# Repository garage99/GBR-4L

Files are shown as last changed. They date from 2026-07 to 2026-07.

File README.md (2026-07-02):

# GBR-4L

GBR-4L is a self-powered USB 2.0 carrier for four Semtech (formerly Sierra
Wireless) AirPrime EM7565 LTE modules. It is intended for use with
OpenMPTCProuter and for manufacture by JLCPCB.

## Rev 1.0 baseline

- Four EM7565 modules in M.2 Key B 3042 sockets
- One nano-SIM per modem
- USB 2.0 High-Speed upstream through a USB Type-C receptacle
- Four-port USB 2.0 hub
- 12 V external input
- Four independently controlled 3.3 V modem power rails
- Per-modem `RESET#`, `W_DISABLE1#`, status indication, and test points
- Four-layer PCB: signal / ground / power / signal
- Preferred outline: 160 mm x 100 mm

> EM7565 is an M.2 module, not a Mini PCIe card. The USB Type-C connector is an
> upstream-facing USB device port (UFP), even though it connects to the host PC.

## Repository layout

- `Hardware/KiCad/GBR-4L/` — KiCad 10 project
- `Hardware/Design/` — requirements, design decisions, and interface definitions
- `Hardware/BOM/` — preliminary and released bills of materials
- `Firmware/` — reserved for optional control firmware
- `Case/` — enclosure and mechanical data

## Current milestone

M1 (part selection and electrical architecture) is in progress. The initial
architecture is recorded in
[`Hardware/Design/GBR-4L_Rev1_Design_Baseline.md`](Hardware/Design/GBR-4L_Rev1_Design_Baseline.md).
No Gerber files are released yet.

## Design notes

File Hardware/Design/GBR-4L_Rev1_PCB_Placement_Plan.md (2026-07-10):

# GBR-4L Rev 1 PCB placement plan

Status: functional placement and plane baseline before detailed routing
Board: 160 mm x 100 mm, 1.6 mm, four copper layers

## Layer intent

| Layer | Primary use |
|---|---|
| F.Cu | Components, USB differential pairs, short local power routing, GND pour |
| In1.Cu | Uninterrupted ground plane |
| In2.Cu | 12 V and five 3.3 V power regions |
| B.Cu | Low-speed control, secondary power routing, GND pour |

Do not split the ground plane below USB, SIM, clock, or modem control traces.
Any layer transition for USB requires adjacent ground stitching vias.

`In1.Cu` now contains the filled `IN1_SOLID_GND` zone, inset 0.5 mm from the
board edge with 0.25 mm local clearance.

`F.Cu` and `B.Cu` also contain filled GND pours inset 0.5 mm from the board
edge. They use 0.25 mm local clearance, 0.30 mm thermal gaps and spokes, and
remove isolated copper islands below 5 mm². The 44 GND stitching vias connect
both outer pours to the uninterrupted `In1.Cu` reference plane.

`In2.Cu` now contains six isolated filled regions:

- `+12V_PROTECTED` and `+3V3_SYS` in the upper half;
- `+3V3_M1` through `+3V3_M4` in four independent modem columns.

Adjacent regions have a 1.0 mm nominal boundary gap and 0.30 mm zone
clearance.

## Via baseline

- Each modem rail (`+3V3_M1` through `+3V3_M4`) has a four-via connection
  array below its M.2 socket: 1.20 mm diameter with a 0.60 mm finished drill.
- `+12V_PROTECTED` has a four-via 1.50/0.80 mm array and `+3V3_SYS` has a
  four-via 1.20/0.60 mm array in their respective upper power regions. A
  second two-via 1.20/0.60 mm `+3V3_SYS` feed connects the USB hub locally,
  with one additional local feed at its reset pull-up.
- The ground plane has 71 stitching, thermal, and local return vias around the board
  perimeter, beside the four modem power arrays, and at both Type-C GND
  contacts: 0.60 mm
  diameter with a 0.30 mm finished drill. This count includes a dedicated via
  and short 0.50 mm ground connection at the USB ESD clamp plus individual
  returns for the shield termination parts, the USB VBUS detector divider, and
  four 0.50/0.25 mm local return vias beside USB2 layer transitions.
- Three additional 0.60/0.30 mm vias connect both Type-C shell ends and the
  R3/C1 termination node between the outer layers on `USB_SHIELD`. This net
  remains intentionally separate from digital GND.
- Two 0.45/0.20 mm signal vias route `USB_VBUS_DET` from the hub to the local
  divider while avoiding the already-routed reset and decoupling area.
- Two additional 0.45/0.20 mm signal vias route `USB_VBUS` from the Type-C
  entry and ESD clamp to the detector divider.
- Four additional 0.45/0.20 mm signal vias route the two Type-C CC pins to
  their pull-down resistors while leaving the USB2 D+/D- corridor open.
- Six 0.40/0.20 mm signal vias gather the duplicated Type-C D+/D- contacts
  into the USB ESD clamp input pins on short provisional `B.Cu` escapes.
- Four additional 0.40/0.20 mm signal vias route the protected upstream USB2
  pair from the ESD clamp output pins to the USB2514B upstream pins.
- Four additional 0.40/0.20 mm signal vias route USB hub downstream port 1 to
  the first M.2 modem socket (`J101`) on provisional `B.Cu` pair segments.
- Four additional 0.40/0.20 mm signal vias route USB hub downstream port 2 to
  the second M.2 modem socket (`J201`) on a separate provisional `B.Cu` lane.
- All 129 vias are through vias from `F.Cu` to `B.Cu`; all nine copper zones
  have been refilled after placement.

These are plane-access points, not completed load connections. The power
arrays must be tied to their regulator and M.2 power pads with short, wide
copper during detailed routing. Add local ground return vias beside USB layer
transitions and decoupling capacitors when their final positions are frozen.

The five 3.3 V contacts on each M.2 socket are now fanned out on `F.Cu` to its
four-via power array. The contact exits use 0.25 mm neck-downs, merge through
0.50 mm branches, and transition to 1.00 mm trunks. This completes the local
socket-to-plane connection for `+3V3_M1` through `+3V3_M4`; the regulator side
of each power region remains to be routed.

## Provisional net classes

- `USB2_HS_PROVISIONAL`: 0.20 mm width / 0.20 mm pair gap. Replace these
  provisional values with the 90-ohm geometry calculated from the selected
  JLCPCB stack-up before routing.
- `MODEM_3V3_POWER`: 1.00 mm track, 1.20/0.60 mm via.
- `INPUT_12V_POWER`: 1.50 mm track, 1.50/0.80 mm via.

These are routing defaults, not proof of current capacity or impedance. Power
rails should use pours where practical and must be validated thermally.

## Mechanical baseline

- Rectangular 160 mm x 100 mm Edge.Cuts outline.
- Four M3 mounting holes, each centered 5 mm from its two adjacent edges.
- Maintain mounting-hole copper and component keep-outs after enclosure review.
- User-accessible connectors, SIM sockets, LEDs, and buttons face board edges.

## Functional placement

1. Place the USB Type-C receptacle and ESD device at one board edge.
2. Place USB2514B, its 24 MHz crystal, and upstream passives immediately behind
   the Type-C receptacle.
3. Arrange the four M.2 3042 sockets so module antenna connectors and coax
   cables remain accessible.
4. Place each nano-SIM socket near its associated modem and at an accessible
   edge.
5. Group the 12 V protection stage and five buck regulators away from USB,
   SIM, and the antenna-connector ends of all modem modules.
6. Keep each buck switch-node copper compact; do not route it on an inner
   layer.

## Footprint status

- TE Connectivity 2199230-1 M.2 Key B footprint is captured from customer
  drawing C-2199230 Rev B4.
- TE Connectivity 2452808-1 nano-SIM footprint is captured from customer
  drawing C-2452808 Rev C1; verify the first incoming part against the land
  pattern before assembly release.
- GCT USB4105 signal and shell tails are captured from the manufacturer
  drawing with the four physically merged contact pairs represented as single
  pads.
- Final 12 V input connector, blade-fuse holder, PMOS, and inductor choices.
- Crystal load-capacitance and package selection.

The current PCB contains the layer stack, outline, mounting holes, all 188
schematic footprints, and all 287 schematic nets. Four M.2 sockets are anchored
on a common line with 30 mm x 42 mm module envelopes reserved below them. The
12 V input and USB Type-C receptacle are anchored at opposite board edges. All
remaining parts are collision-free in the upper component band.

The USBLC6-2SC6 ESD clamp (`U1`) is now placed directly behind the Type-C
receptacle. Its ground pin has a dedicated plane via. The `+3V3_SYS` inductor
`L801` was relocated within the same upper power region to open this protected
USB entry corridor.

The Type-C upstream D+/D- contacts are routed from `J1` to the input side of
the ESD clamp (`U1`) using short 0.15 mm provisional `F.Cu` stubs and `B.Cu`
gathering traces. The protected side of `U1` is also routed to `U2` pins 30
and 31 with provisional 0.15 mm `B.Cu` pair segments and short `F.Cu` pin
escapes. This completes the upstream USB2 electrical path from connector to
hub, but the geometry must still be recalculated and tuned after the final
JLCPCB stack-up is selected. Four local GND return vias are placed next to the
connector-side and hub-side USB2 layer transitions.

The 1 MΩ / 4.7 nF shield termination (`R3`/`C1`) is placed below the Type-C
receptacle. Both parts have individual GND vias, while their `USB_SHIELD` pads
join at a dedicated via and connect to the shell on `B.Cu`.

The two 5.1 kΩ Type-C pull-downs (`R1`/`R2`) are grouped below the connector
and each has an individual GND via. Their `USB_CC1` and `USB_CC2` sides are
routed to the Type-C receptacle with short `F.Cu` escapes and `B.Cu` vertical
runs.

USB hub downstream port 1 (`USB_M1_D+`/`USB_M1_D-`) is routed from `U2` pins
1 and 2 to `J101` pins 7 and 9. The route uses short `F.Cu` pin escapes, then
travels on `B.Cu` along the lane above the M.2 sockets before returning to the
connector pads. This is also provisional USB2 geometry pending final stack-up
and length/impedance tuning.

USB hub downstream port 2 (`USB_M2_D+`/`USB_M2_D-`) is routed from `U2` pins
3 and 4 to `J201` pins 7 and 9. It follows the same provisional style as port
1, but uses an offset `B.Cu` lane so the two modem USB2 routes do not overlap.

The USB2514B hub (`U2`) is placed at (145 mm, 55 mm), between the Type-C entry
and four modem sockets. Its 4.1 mm exposed GND pad contains a 2 x 2 array of
0.60/0.30 mm thermal vias. These vias are open on the component side and
tented on `B.Cu`; confirm the selected assembler accepts this via-in-pad
construction before release.

The 24 MHz crystal (`Y1`) and 12 pF C0G load capacitors (`C4`/`C5`) are placed
immediately left of `U2`. Both oscillator traces are routed directly on
`F.Cu`, without vias, and each load capacitor has an individual GND via.

The hub reference filter and bias parts (`C2`, `C3`, and `R6`) are also placed
at their associated `U2` pins. Each sensitive node is routed directly on
`F.Cu`, and every part has its own short GND return and plane via.

Four 100 nF capacitors (`C7` through `C10`) and the 4.7 µF bulk bypass (`C11`)
surround `U2`. Their 3.3 V branches are routed directly to the nearest hub
power pins, and all five parts use individual GND vias. The resulting
decoupling network is tied to the `+3V3_SYS` inner region through two local
power vias and a 1.00 mm `F.Cu` trunk.

The hub reset network (`R7`/`C6`) is placed above the right side of `U2`.
`HUB_RESET#` uses a short `B.Cu` escape between two vias to pass the
decoupling area, with a local `+3V3_SYS` pull-up via and a dedicated capacitor
GND return.

The USB VBUS detector divider (`R4`/`R5`) is placed in the same USB support
area near `U2`. Its midpoint is routed to `U2` pin 27 (`USB_VBUS_DET`) using
two small signal vias and a short `B.Cu` segment. `R5` has a local GND return
via. The `USB_VBUS` side of `R4` is now tied to both Type-C VBUS contacts and
the USB ESD clamp VBUS pin through a short `F.Cu` entry trunk and a `B.Cu`
escape to the divider.

This is the functional anchor baseline, not the final local placement. Buck
converter loops, hub passives, SIM protection, modem decoupling, buttons, and
LEDs must next be pulled tightly around their associated primary components.

The two 0.65 mm USB4105 locating holes are presently shown on `F.Fab` rather
than emitted as NPTH holes. KiCad 10.0.4 CLI aborts during DRC when those NPTH
holes are combined with the adjacent fine-pitch pads. They must be restored as
NPTH holes and verified in a newer KiCad release before fabrication output.

Electrical nets remain authoritative in the schematic. The current PCB has
all 287 schematic nets imported through KiCad's **Update PCB from Schematic**
workflow.

## Placement review gate

- Verify the imported set remains at 287 schematic nets after any schematic
  change and **Update PCB from Schematic** operation.
- Verify zero missing footprint assignments.
- Check M.2 module and antenna-cable keep-outs in 3D.
- Confirm SIM insertion direction and finger clearance.
- Confirm all edge controls against the enclosure.
- Calculate 90-ohm USB geometry from the selected JLCPCB stack-up.
- Run PCB DRC before beginning routing.

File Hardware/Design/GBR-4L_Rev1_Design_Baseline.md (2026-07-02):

# GBR-4L Rev 1.0 design baseline

Status: engineering baseline for schematic capture<br>
Target CAD: KiCad 10<br>
Target fabrication: JLCPCB, four layers

## 1. Purpose

GBR-4L connects four AirPrime EM7565 LTE modems to one OpenMPTCProuter host over
USB 2.0. Each modem has its own nano-SIM, controllable power rail, reset,
wireless-disable signal, status LED, and measurement points.

This document resolves ambiguities in the original project brief. It is the
source of truth until superseded by an approved revision.

## 2. Corrections to the original brief

1. **Module form factor:** EM7565 is M.2 Key B, size 3042. It is not Mini PCIe.
2. **USB role:** the Type-C receptacle is an upstream-facing device port (UFP).
   The attached computer/OpenMPTCProuter is the USB host.
3. **RF routing:** cellular RF remains on the EM7565 module and exits through
   its miniature coaxial connectors. The carrier PCB does not route cellular
   RF transmission lines. Placement must preserve antenna-cable access and
   keep switching regulators away from the module antenna-connector end.
4. **Data-rate expectation:** Rev 1 uses USB 2.0 High-Speed. Aggregate practical
   throughput is therefore bounded by the single USB 2.0 upstream link and
   will be far below the sum of four Cat-12 modem peak rates.

## 3. Electrical architecture

### 3.1 Power tree

Nominal input is 12 V DC. Design input range is 10.8 V to 13.2 V.

```text
12V_IN
  |
  +-- input fuse / reverse-polarity protection / TVS
  |
  +-- 3 A buck 1 --> MODEM_1_3V3
  +-- 3 A buck 2 --> MODEM_2_3V3
  +-- 3 A buck 3 --> MODEM_3_3V3
  +-- 3 A buck 4 --> MODEM_4_3V3
  +-- 3 A buck 5 --> SYS_3V3 (USB hub, indicators, control)
```

Each modem supply:

- nominal 3.3 V;
- sized for at least 1.5 A continuous;
- tolerates 2.5 A inrush;
- independently enabled;
- includes local bulk and high-frequency decoupling at the M.2 socket;
- exposes voltage, ground, enable, and power-good test points.

Five TPS56339 3 A synchronous buck regulators are the initial choice. Four
identical channels feed one modem each and the fifth feeds system logic. The
device has internal compensation and a 5 ms soft-start. Each modem channel uses
its `EN` pin for independent hard power control.

The system must not draw modem operating power from USB VBUS. VBUS is used only
for attach detection and hub requirements.

### 3.2 USB

Initial hub controller: Microchip USB2514B, four downstream ports, USB 2.0
High-Speed, self-powered configuration.

Type-C UFP requirements:

- USB 2.0-only receptacle;
- 5.1 kOhm pull-down on CC1 and CC2;
- low-capacitance ESD protection on D+, D-, CC1, CC2, and VBUS;
- A6/B6 tied as D+ and A7/B7 tied as D- at the receptacle;
- controlled 90 Ohm differential routing over uninterrupted ground;
- no USB Power Delivery controller.

All four hub downstream pairs route directly to the corresponding EM7565 USB
2.0 pins. Test pads must be stubs of minimum practical length and are optional
for production.

### 3.3 Modem control

For each slot:

- `FULL_CARD_POWER_OFF#`: default deasserted; available to the control header;
- `RESET#`: normally deasserted, with local momentary reset and header access;
- `W_DISABLE1#`: normally deasserted, with header access;
- `WAN_LED#`: drives an external LED through a transistor or buffer;
- unused/reserved M.2 pins remain no-connect as required by the EM7565
  specification.

Controls must have deterministic defaults so all four modems enumerate without
an external controller. A header permits later GPIO control from the router or
an optional controller board.

### 3.4 SIM

One front-entry push-pull nano-SIM socket with a card-detect switch is assigned
to the primary SIM interface of each EM7565. The baseline candidate is TE
Connectivity 2452808-1.

- Protect `UIM_PWR`, `UIM_DATA`, `UIM_CLK`, and `UIM_RESET` with a
  low-capacitance SIM ESD array placed at the socket.
- Place SIM decoupling at the socket.
- Keep `UIM_DATA` and `UIM_CLK` capacitance low.
- Keep total UIM power and ground path impedance below 1 Ohm.
- Route each SIM only to its associated modem; do not multiplex in Rev 1.
- The 2452808-1 detect contact is open without a card and closes to its C5/GND
  contact when a card is inserted.

## 4. Power budget

| Load | Quantity | Design current each | Total at rail |
|---|---:|---:|---:|
| EM7565 continuous maximum | 4 | 1.5 A at 3.3 V | 6.0 A |
| EM7565 inrush allowance | 4 | 2.5 A transient | sequence turn-on |
| USB hub and logic | 1 set | 0.5 A budget at 3.3 V | 0.5 A |

The four modem rails represent 19.8 W at full continuous load. Including
conversion loss, logic, margin, and start-up behavior, the external adapter
shall be rated **12 V, 4 A minimum**; **12 V, 5 A recommended**.

All four modem rails must not start simultaneously. Default sequencing is
approximately 250 ms between channels, implemented by RC delays or the optional
controller. The exact method is finalized during schematic review.

## 5. PCB constraints

- Four layers: Top / solid GND / power / Bottom.
- Keep USB pairs on a single layer where possible and never cross a plane split.
- Calculate USB geometry from the selected JLCPCB stack-up before routing.
- Keep buck-converter switch nodes compact and away from M.2 antenna connectors,
  SIM traces, USB pairs, and board edges used by antenna cables.
- Use wide copper pours and multiple vias for every modem supply and return.
- Provide thermal copper and via arrays under exposed-pad regulators.
- Keep a mechanical keep-out above and below each 42 mm x 30 mm module.
- Preserve access for three module antenna connectors and their cables.
- Preferred board size is 160 mm x 100 mm; increase only after placement review.

## 6. Verification gates

Before Gerber release:

1. Confirm exact EM7565 SKU and current product technical specification.
2. Confirm M.2 connector contact height and mounting hardware against enclosure.
3. Review every EM7565 reserved pin and power/control default.
4. Run ERC with no unexplained errors.
5. Validate power converters for 2.5 A load steps and staggered start-up.
6. Confirm USB2514B self-powered strap/EEPROM configuration.
7. Run USB differential-impedance and return-path review.
8. Run PCB DRC with the selected JLCPCB four-layer rules.
9. Generate and inspect BOM, CPL, Gerber, drill, and fabrication drawings.
10. Bench-test one modem first, then all four at maximum transmit duty cycle.

## 7. Reference documents

- Semtech/Sierra Wireless, AirPrime EM7565 Product Technical Specification.
- Microchip, USB251xB/xBi USB 2.0 Hi-Speed Hub Controller Data Sheet.
- Texas Instruments, TPS56339 3 A Synchronous Step-Down Converter
  Data Sheet.
- USB Type-C Cable and Connector Specification.

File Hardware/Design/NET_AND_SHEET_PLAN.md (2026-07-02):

# Net and schematic sheet plan

## Sheet mapping

| Existing KiCad sheet | Rev 1 responsibility |
|---|---|
| `Power_sch.kicad_sch` | 12 V input protection, two dual modem bucks, auxiliary 3.3 V, sequencing |
| `USB.kicad_sch` | Type-C UFP, ESD, USB2514B, crystal/clock, hub straps |
| `LTE_SLOT1.kicad_sch` | M.2 Key B socket 1, local power, controls, USB |
| `LTE_SLOT2.kicad_sch` | M.2 Key B socket 2, local power, controls, USB |
| `LTE_SLOT3.kicad_sch` | M.2 Key B socket 3, local power, controls, USB |
| `LTE_SLOT4.kicad_sch` | M.2 Key B socket 4, local power, controls, USB |
| `SIM.kicad_sch` | Four nano-SIM sockets, ESD, decoupling |
| `LED_RESET.kicad_sch` | Status LEDs, reset switches, W_DISABLE controls, GPIO header |

## Global net naming

- Input/system: `+12V_IN`, `+3V3_SYS`, `GND`, `USB_VBUS_SENSE`
- Modem rails: `+3V3_M1` through `+3V3_M4`
- Hub downstream USB: `USB_M1_D+/-` through `USB_M4_D+/-`
- Hub upstream USB: `USB_UP_D+`, `USB_UP_D-`
- Per-slot control: `M1_PWR_EN`, `M1_PWR_GOOD`, `M1_RESET#`,
  `M1_W_DISABLE#`, `M1_FULL_CARD_POWER_OFF#`, `M1_WAN_LED#` (repeat M2-M4)
- Per-slot SIM: `M1_UIM_PWR`, `M1_UIM_DATA`, `M1_UIM_CLK`,
  `M1_UIM_RESET`, `M1_SIM_DETECT` (repeat M2-M4)

Active-low names retain `#` to match the module documentation.

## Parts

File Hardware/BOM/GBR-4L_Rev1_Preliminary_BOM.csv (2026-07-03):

Status | Functional_Block | Qty | Manufacturer | Manufacturer_Part_Number | Description | Package_or_Form | Selection_Notes
SELECTED | LTE modem | 4 | Semtech / Sierra Wireless | EM7565 | Cat-12 LTE modem | M.2 Key B 3042 | Exact regional SKU and firmware must be confirmed before purchase
SELECTED | M.2 socket | 4 | TE Connectivity | 2199230-1 | M.2 Key B socket | 67-contact SMT 4.2 mm height | Project footprint captured from C-2199230 Rev B4; verify availability
SELECTED | USB hub | 1 | Microchip | USB2514B-I/M2 | Four-port USB 2.0 High-Speed hub controller | SQFN-36 | Production device; self-powered configuration
SELECTED | 3.3 V buck regulator | 5 | Texas Instruments | TPS56339DDCR | 3 A synchronous step-down regulator | SOT-23-THN-6 | Four modem rails plus one system rail; 12 V to 3.3 V; internal compensation
CANDIDATE | USB ESD | 1 | STMicroelectronics | USBLC6-2SC6 | Low-capacitance USB 2.0 ESD protection | SOT-23-6 | Protect upstream D+ and D-
CANDIDATE | SIM ESD | 4 | STMicroelectronics | ESDA6V1-5SC6 | Five-line ESD protection array | SOT-23-6 | Confirm capacitance against SIM interface
CANDIDATE | USB Type-C receptacle | 1 | GCT | USB4105-GF-A | USB 2.0 Type-C receptacle | 16-pin SMT | Verify JLC assembly support and shell tabs
SELECTED | nano-SIM socket | 4 | TE Connectivity | 2452808-1 | Front-entry push-pull nano-SIM socket with card detect | SMT 1.37 mm height | Project footprint captured from C-2452808 Rev C1; switch closes to C5/GND when a card is inserted
CANDIDATE | Input TVS | 1 | Littelfuse | SMBJ15A | 15 V unidirectional TVS | SMB | Recheck standoff voltage for selected 12 V adapter
CANDIDATE | Input fuse | 1 |  | 5 A time-delay blade fuse | Replaceable input overcurrent protection | ATO blade holder | Freeze fuse and holder after adapter and load-step testing
CANDIDATE | CC resistors | 2 |  | 5.1k 1% | USB Type-C Rd resistor | 0603 | One each on CC1 and CC2
CANDIDATE | Hub crystal | 1 |  | 24 MHz crystal | 3225 | Select from USB2514B approved load parameters
CANDIDATE | Status LED buffer | 4 | onsemi | MMBT3906LT1G | PNP transistor for active-low modem status | SOT-23 | Verify JLCPCB assembly stock or approve equivalent
CANDIDATE | Local control switch | 8 | Omron | B3U-1000P | Normally-open tactile switch | SMD | Four reset and four RF-disable controls; verify actuator height
CANDIDATE | Modem status LED | 4 |  | Green LED | Per-modem WWAN status indicator | 0603 | Select brightness and current at prototype review

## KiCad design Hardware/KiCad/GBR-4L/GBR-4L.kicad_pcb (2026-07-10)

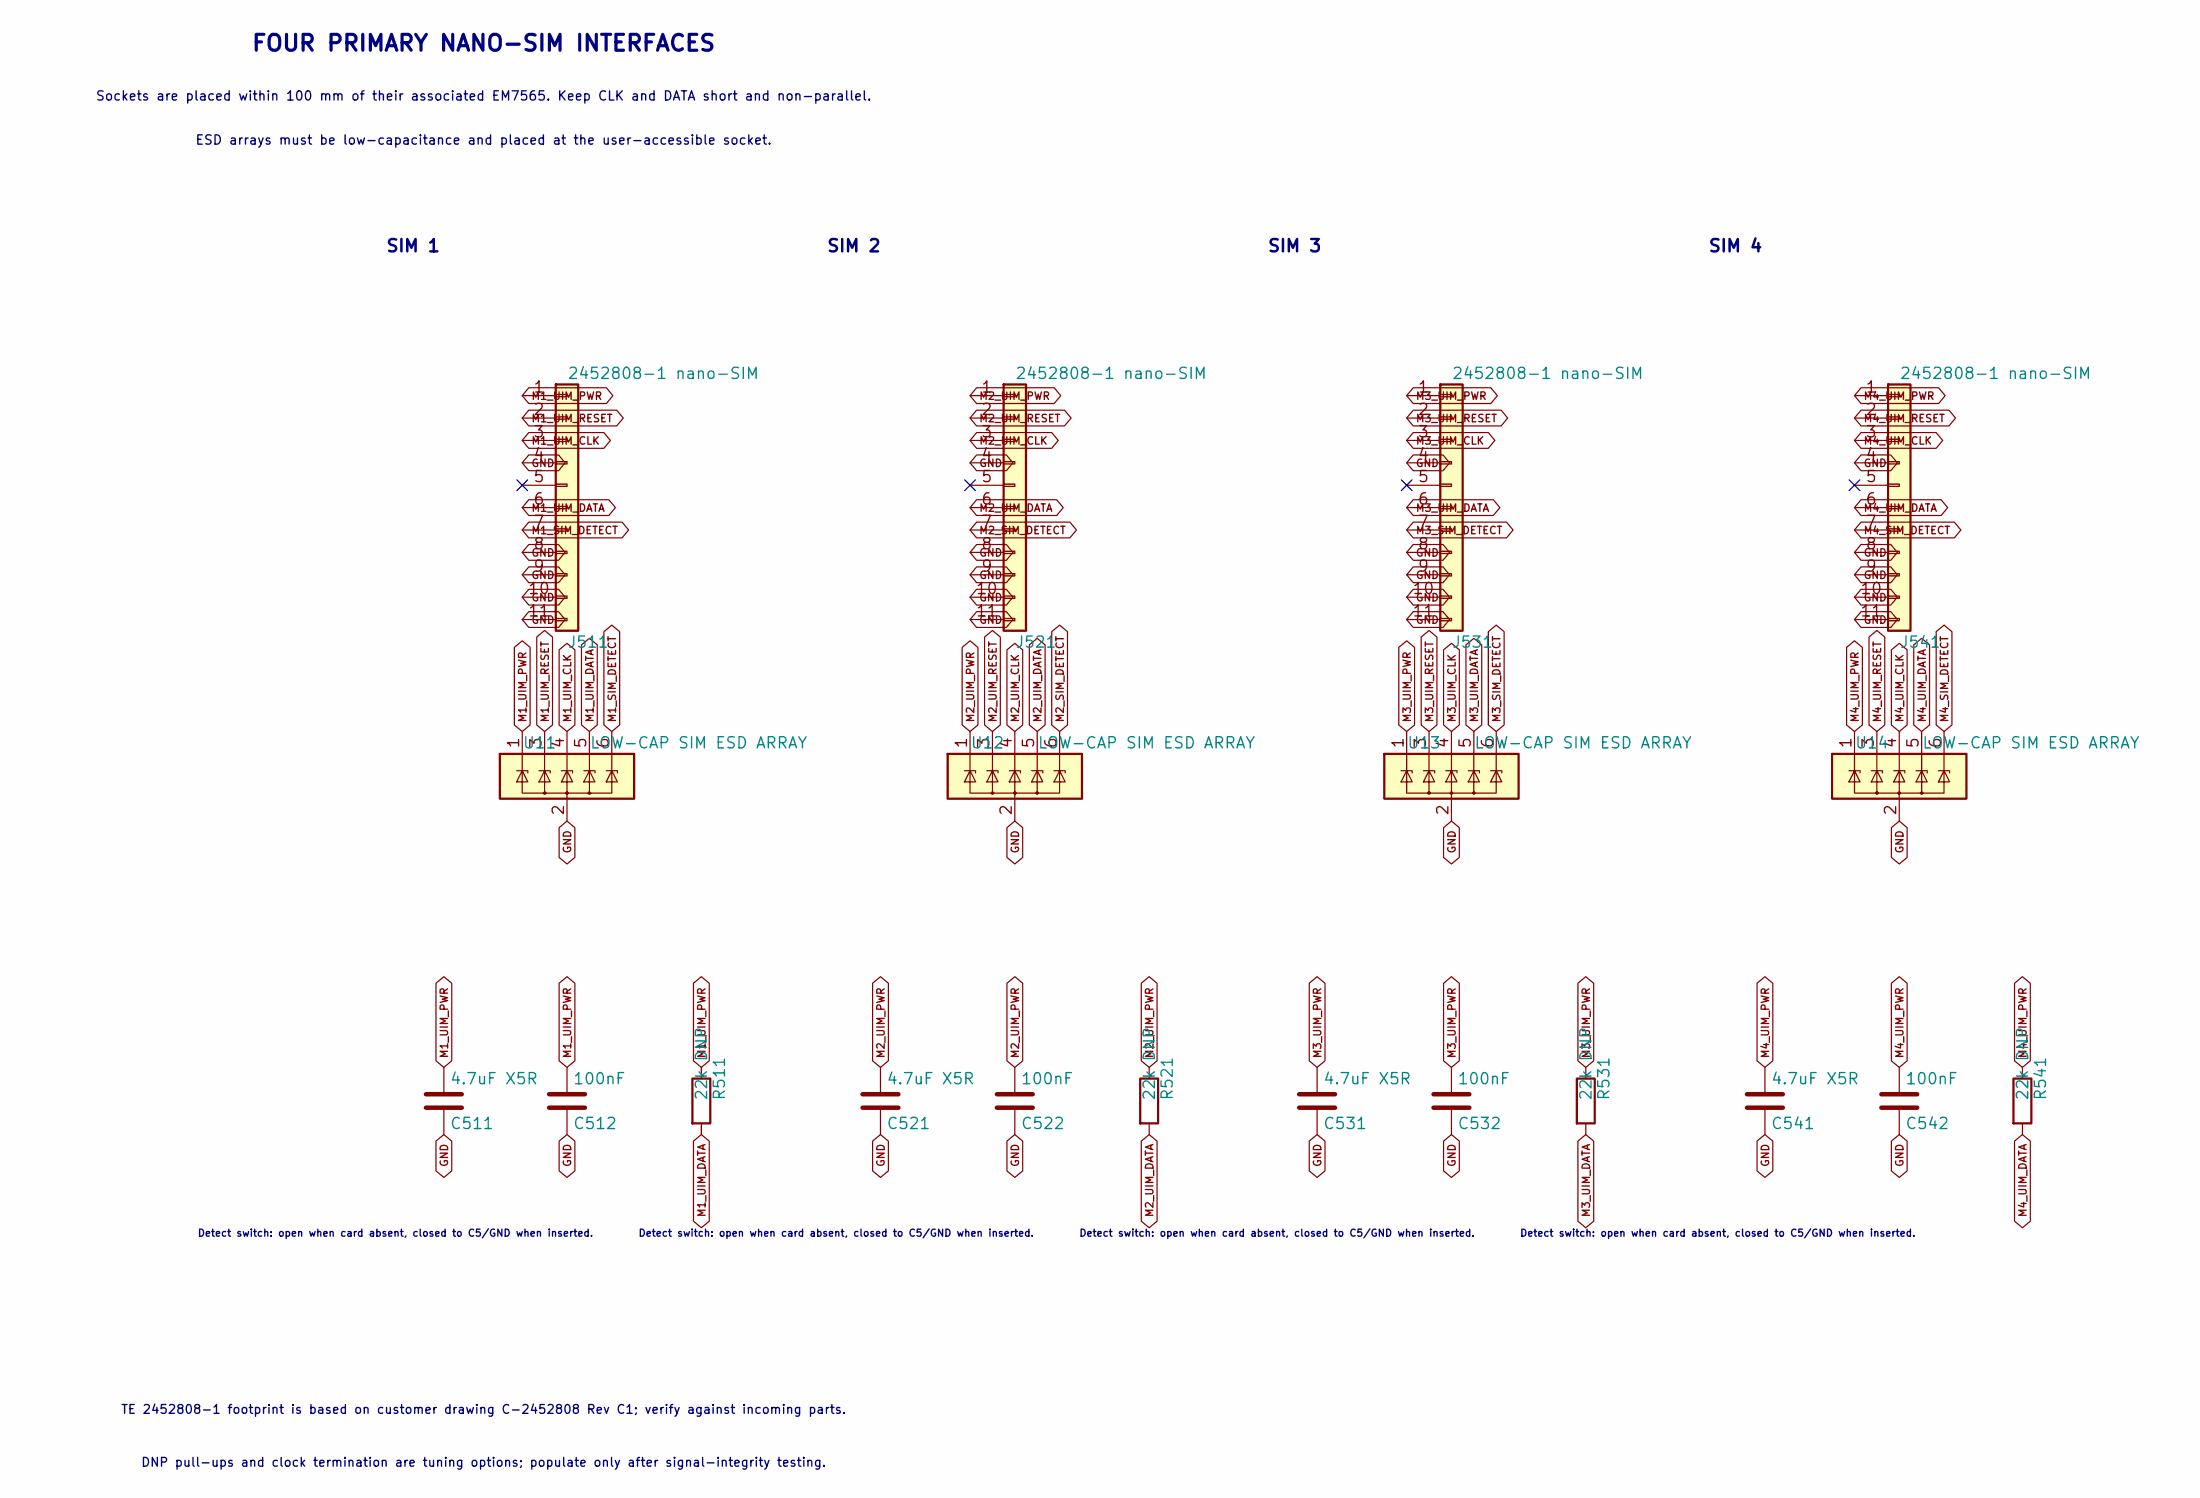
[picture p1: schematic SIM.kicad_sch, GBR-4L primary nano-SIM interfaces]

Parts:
C511, C521, C531, C541: 4.7uF X5R; C_0805_2012Metric
C512, C522, C532, C542: 100nF; C_0603_1608Metric
J511, J521, J531, J541: 2452808-1 nano-SIM; TE_2452808-1
R511, R521, R531, R541: 22k DNP; R_0603_1608Metric
U11, U12, U13, U14: LOW-CAP SIM ESD ARRAY; SOT-23-6

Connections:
GND: C511.2, C512.2, C521.2, C522.2, C531.2, C532.2, C541.2, C542.2, J511.4, J511.8, J511.9, J511.10, J511.11, J521.4, J521.8, J521.9, J521.10, J521.11, J531.4, J531.8, J531.9, J531.10, J531.11, J541.4, J541.8, J541.9, J541.10, J541.11, U11.2 (GND), U12.2 (GND), U13.2 (GND), U14.2 (GND); also elsewhere on the board
M1_SIM_DETECT: J511.7, U11.6 (IO5); also elsewhere on the board
M1_UIM_CLK: J511.3, U11.4 (IO3); also elsewhere on the board
M1_UIM_DATA: J511.6, R511.2, U11.5 (IO4); also elsewhere on the board
M1_UIM_PWR: C511.1, C512.1, J511.1, R511.1, U11.1 (IO1); also elsewhere on the board
M1_UIM_RESET: J511.2, U11.3 (IO2); also elsewhere on the board
M2_SIM_DETECT: J521.7, U12.6 (IO5); also elsewhere on the board
M2_UIM_CLK: J521.3, U12.4 (IO3); also elsewhere on the board
M2_UIM_DATA: J521.6, R521.2, U12.5 (IO4); also elsewhere on the board
M2_UIM_PWR: C521.1, C522.1, J521.1, R521.1, U12.1 (IO1); also elsewhere on the board
M2_UIM_RESET: J521.2, U12.3 (IO2); also elsewhere on the board
M3_SIM_DETECT: J531.7, U13.6 (IO5); also elsewhere on the board
M3_UIM_CLK: J531.3, U13.4 (IO3); also elsewhere on the board
M3_UIM_DATA: J531.6, R531.2, U13.5 (IO4); also elsewhere on the board
M3_UIM_PWR: C531.1, C532.1, J531.1, R531.1, U13.1 (IO1); also elsewhere on the board
M3_UIM_RESET: J531.2, U13.3 (IO2); also elsewhere on the board
M4_SIM_DETECT: J541.7, U14.6 (IO5); also elsewhere on the board
M4_UIM_CLK: J541.3, U14.4 (IO3); also elsewhere on the board
M4_UIM_DATA: J541.6, R541.2, U14.5 (IO4); also elsewhere on the board
M4_UIM_PWR: C541.1, C542.1, J541.1, R541.1, U14.1 (IO1); also elsewhere on the board
M4_UIM_RESET: J541.2, U14.3 (IO2); also elsewhere on the board

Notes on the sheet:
Detect switch: open when card absent, closed to C5/GND when inserted.
DNP pull-ups and clock termination are tuning options; populate only after signal-integrity testing.
TE 2452808-1 footprint is based on customer drawing C-2452808 Rev C1; verify against incoming parts.
SIM 2
FOUR PRIMARY NANO-SIM INTERFACES
Sockets are placed within 100 mm of their associated EM7565. Keep CLK and DATA short and non-parallel.
ESD arrays must be low-capacitance and placed at the user-accessible socket.
SIM 4
SIM 3
SIM 1

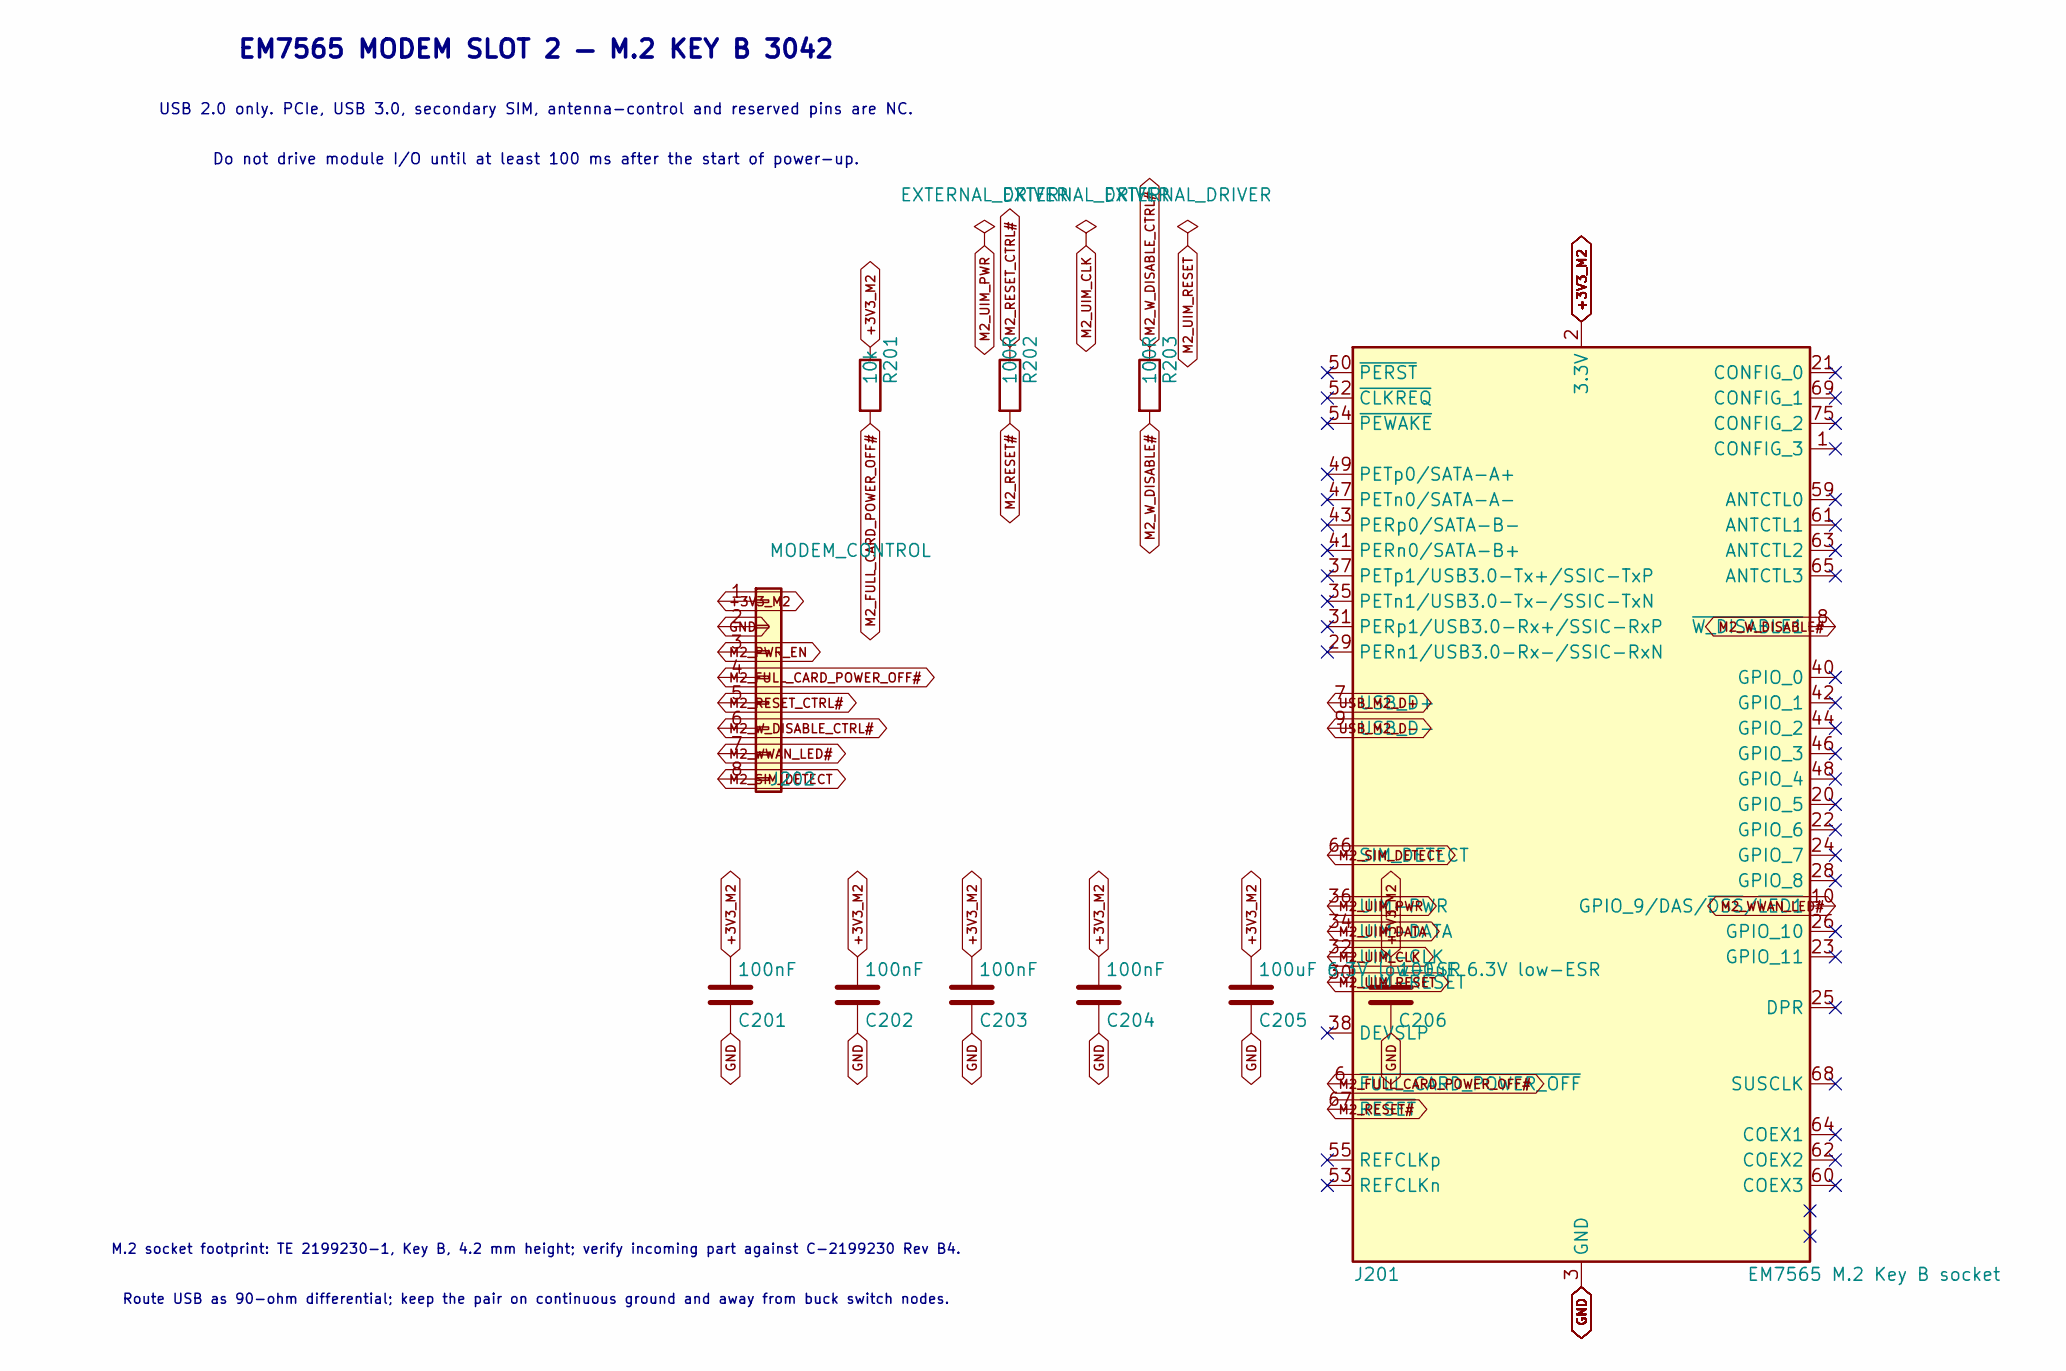
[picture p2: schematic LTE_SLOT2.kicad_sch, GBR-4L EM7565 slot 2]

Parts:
C201, C202, C203, C204: 100nF; C_0603_1608Metric
C205, C206: 100uF 6.3V low-ESR; C_1210_3225Metric
J201: EM7565 M.2 Key B socket; TE_2199230-1_M2_Key-B
J202: MODEM_CONTROL; PinHeader_1x08_P2.54mm_Vertical
R201: 10k; R_0603_1608Metric
R202, R203: 100R; R_0603_1608Metric

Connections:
+3V3_M2: C201.1, C202.1, C203.1, C204.1, C205.1, C206.1, J201.2 (3.3V), J201.4 (3.3V), J201.70 (3.3V), J201.72 (3.3V), J201.74 (3.3V), J202.1, R201.1; also elsewhere on the board
GND: C201.2, C202.2, C203.2, C204.2, C205.2, C206.2, J201.3 (GND), J201.5 (GND), J201.11 (GND), J201.27 (GND), J201.33 (GND), J201.39 (GND), J201.45 (GND), J201.51 (GND), J201.57 (GND), J201.71 (GND), J201.73 (GND), J202.2; also elsewhere on the board
M2_FULL_CARD_POWER_OFF#: J201.6 (~FULL_CARD_POWER_OFF), J202.4, R201.2
M2_PWR_EN: J202.3; also elsewhere on the board
M2_RESET#: J201.67 (~RESET), R202.2
M2_RESET_CTRL#: J202.5, R202.1; also elsewhere on the board
M2_SIM_DETECT: J201.66 (SIM_DETECT), J202.8; also elsewhere on the board
M2_UIM_CLK: J201.32 (UIM-CLK); also elsewhere on the board
M2_UIM_DATA: J201.34 (UIM-DATA); also elsewhere on the board
M2_UIM_PWR: J201.36 (UIM-PWR); also elsewhere on the board
M2_UIM_RESET: J201.30 (UIM-RESET); also elsewhere on the board
M2_WWAN_LED#: J201.10 (GPIO_9/DAS/~DSS/~LED1), J202.7; also elsewhere on the board
M2_W_DISABLE#: J201.8 (~W_DISABLE1), R203.2
M2_W_DISABLE_CTRL#: J202.6, R203.1; also elsewhere on the board
USB_M2_D+: J201.7 (USB_D+); also elsewhere on the board
USB_M2_D-: J201.9 (USB_D-); also elsewhere on the board

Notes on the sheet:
Route USB as 90-ohm differential; keep the pair on continuous ground and away from buck switch nodes.
Do not drive module I/O until at least 100 ms after the start of power-up.
EM7565 MODEM SLOT 2 — M.2 KEY B 3042
M.2 socket footprint: TE 2199230-1, Key B, 4.2 mm height; verify incoming part against C-2199230 Rev B4.
USB 2.0 only. PCIe, USB 3.0, secondary SIM, antenna-control and reserved pins are NC.

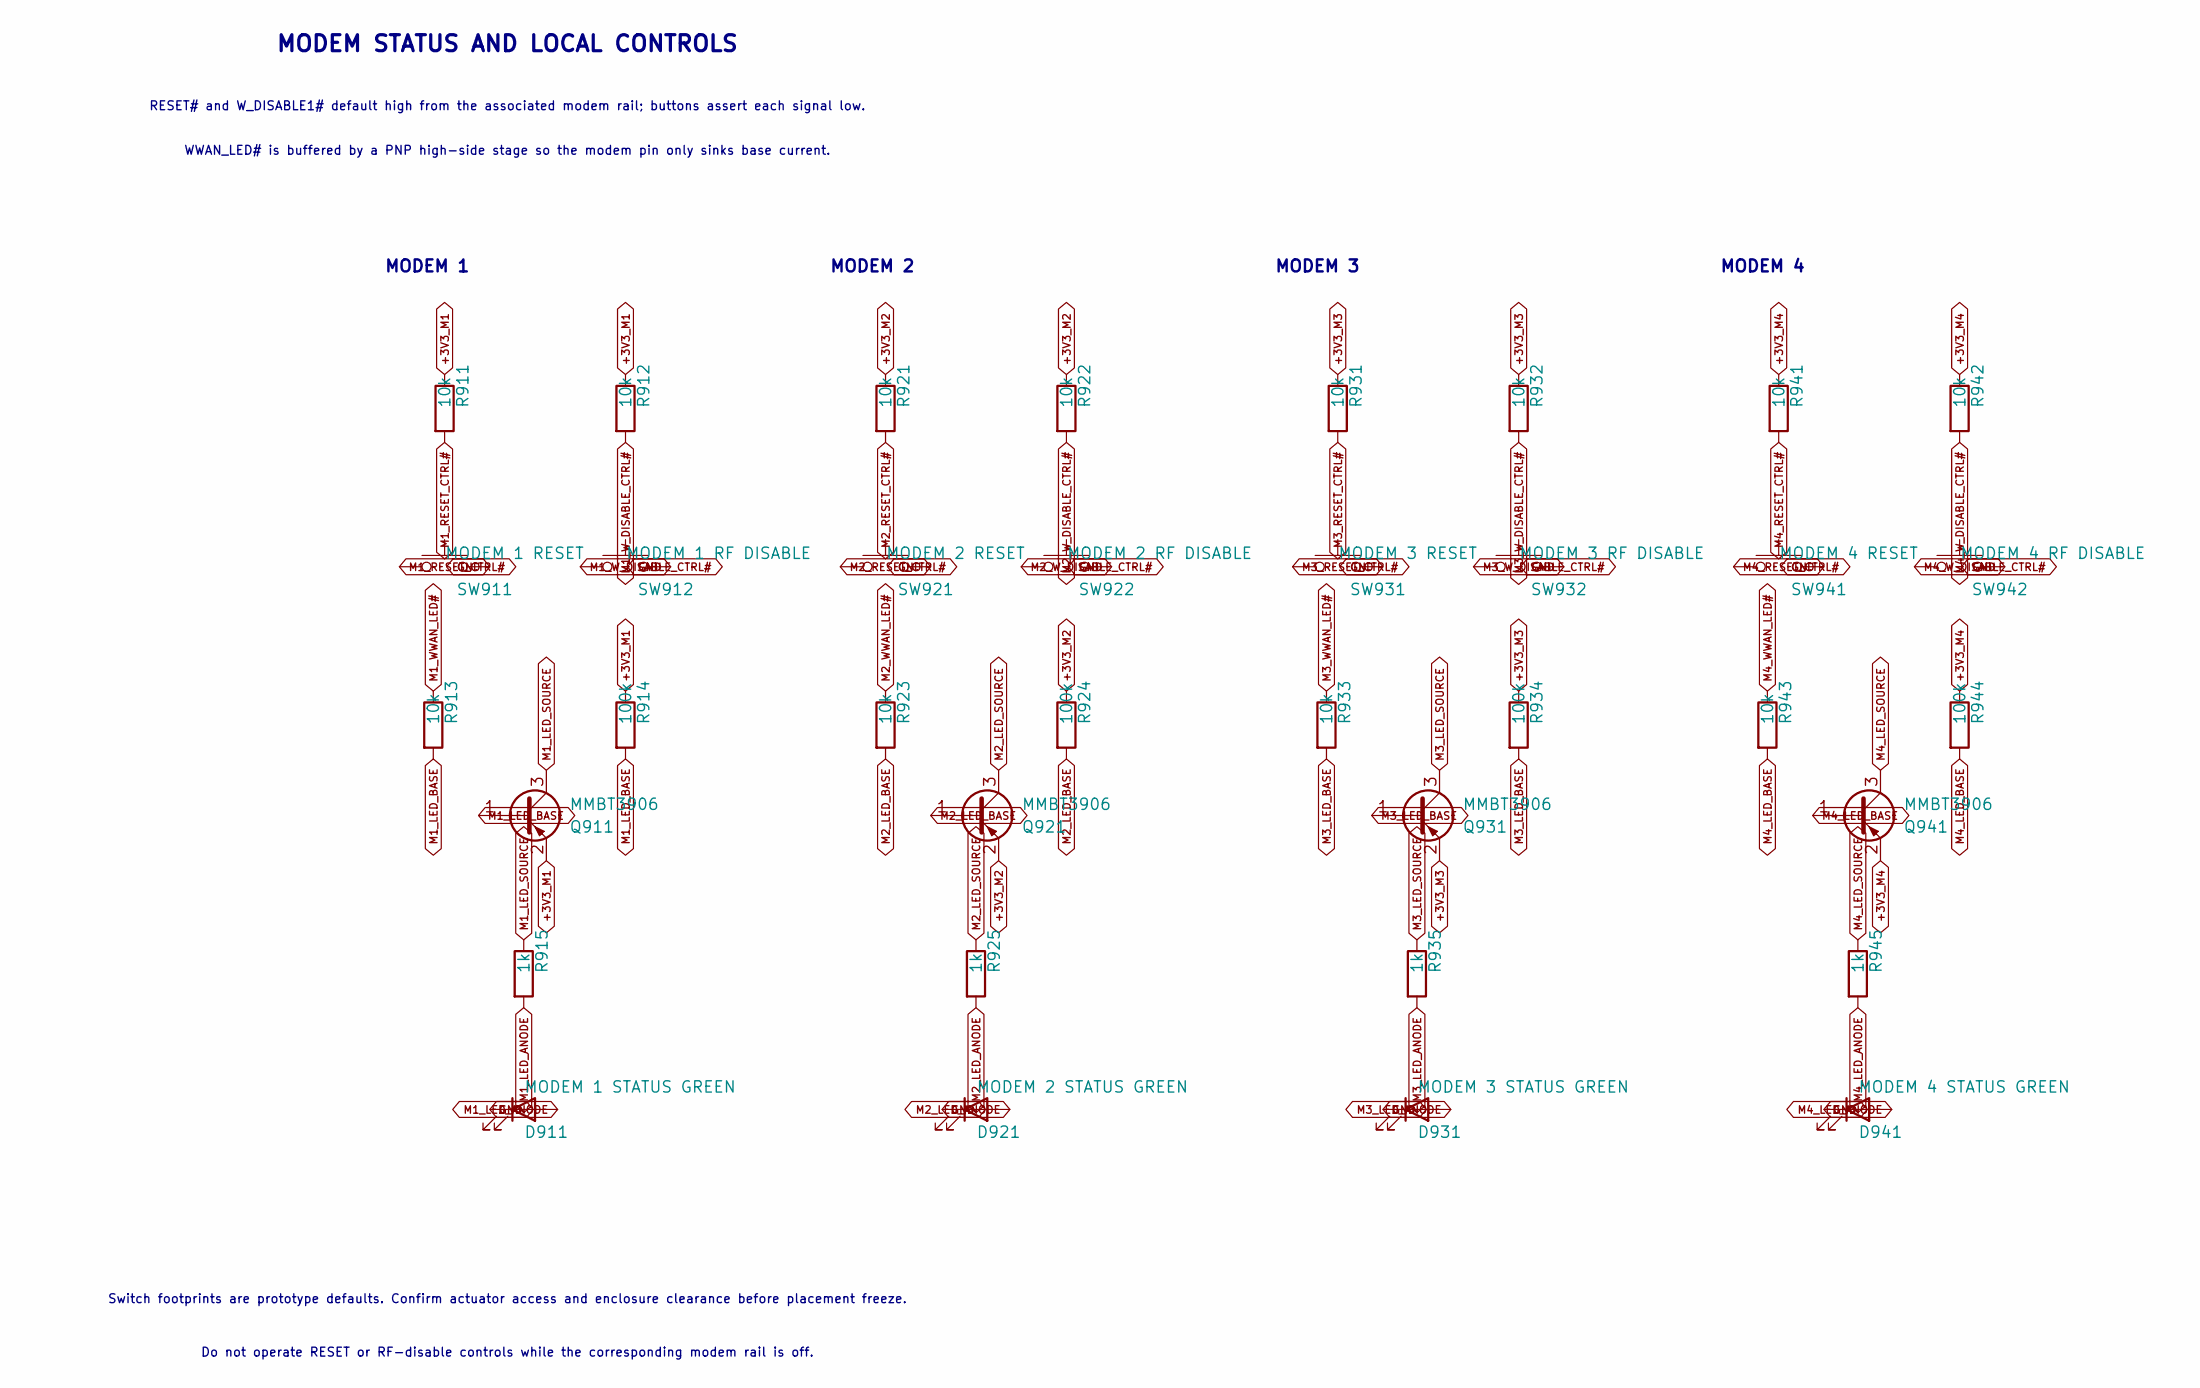
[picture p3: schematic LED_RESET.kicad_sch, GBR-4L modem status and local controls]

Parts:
D911: MODEM 1 STATUS GREEN; LED_0603_1608Metric
D921: MODEM 2 STATUS GREEN; LED_0603_1608Metric
D931: MODEM 3 STATUS GREEN; LED_0603_1608Metric
D941: MODEM 4 STATUS GREEN; LED_0603_1608Metric
Q911, Q921, Q931, Q941: MMBT3906; SOT-23
R911, R912, R913, R921, R922, R923, R931, R932, R933, R941, R942, R943: 10k; R_0603_1608Metric
R914, R924, R934, R944: 100k; R_0603_1608Metric
R915, R925, R935, R945: 1k; R_0603_1608Metric
SW911: MODEM 1 RESET; SW_SPST_B3U-1000P
SW912: MODEM 1 RF DISABLE; SW_SPST_B3U-1000P
SW921: MODEM 2 RESET; SW_SPST_B3U-1000P
SW922: MODEM 2 RF DISABLE; SW_SPST_B3U-1000P
SW931: MODEM 3 RESET; SW_SPST_B3U-1000P
SW932: MODEM 3 RF DISABLE; SW_SPST_B3U-1000P
SW941: MODEM 4 RESET; SW_SPST_B3U-1000P
SW942: MODEM 4 RF DISABLE; SW_SPST_B3U-1000P

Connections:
+3V3_M1: Q911.2 (E), R911.1, R912.1, R914.1; also elsewhere on the board
+3V3_M2: Q921.2 (E), R921.1, R922.1, R924.1; also elsewhere on the board
+3V3_M3: Q931.2 (E), R931.1, R932.1, R934.1; also elsewhere on the board
+3V3_M4: Q941.2 (E), R941.1, R942.1, R944.1; also elsewhere on the board
GND: D911.1 (K), D921.1 (K), D931.1 (K), D941.1 (K), SW911.2, SW912.2, SW921.2, SW922.2, SW931.2, SW932.2, SW941.2, SW942.2; also elsewhere on the board
M1_LED_ANODE: D911.2 (A), R915.2
M1_LED_BASE: Q911.1 (B), R913.2, R914.2
M1_LED_SOURCE: Q911.3 (C), R915.1
M1_RESET_CTRL#: R911.2, SW911.1; also elsewhere on the board
M1_WWAN_LED#: R913.1; also elsewhere on the board
M1_W_DISABLE_CTRL#: R912.2, SW912.1; also elsewhere on the board
M2_LED_ANODE: D921.2 (A), R925.2
M2_LED_BASE: Q921.1 (B), R923.2, R924.2
M2_LED_SOURCE: Q921.3 (C), R925.1
M2_RESET_CTRL#: R921.2, SW921.1; also elsewhere on the board
M2_WWAN_LED#: R923.1; also elsewhere on the board
M2_W_DISABLE_CTRL#: R922.2, SW922.1; also elsewhere on the board
M3_LED_ANODE: D931.2 (A), R935.2
M3_LED_BASE: Q931.1 (B), R933.2, R934.2
M3_LED_SOURCE: Q931.3 (C), R935.1
M3_RESET_CTRL#: R931.2, SW931.1; also elsewhere on the board
M3_WWAN_LED#: R933.1; also elsewhere on the board
M3_W_DISABLE_CTRL#: R932.2, SW932.1; also elsewhere on the board
M4_LED_ANODE: D941.2 (A), R945.2
M4_LED_BASE: Q941.1 (B), R943.2, R944.2
M4_LED_SOURCE: Q941.3 (C), R945.1
M4_RESET_CTRL#: R941.2, SW941.1; also elsewhere on the board
M4_WWAN_LED#: R943.1; also elsewhere on the board
M4_W_DISABLE_CTRL#: R942.2, SW942.1; also elsewhere on the board

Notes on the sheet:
Switch footprints are prototype defaults. Confirm actuator access and enclosure clearance before placement freeze.
Do not operate RESET or RF-disable controls while the corresponding modem rail is off.
WWAN_LED# is buffered by a PNP high-side stage so the modem pin only sinks base current.
MODEM 2
MODEM 3
MODEM 4
RESET# and W_DISABLE1# default high from the associated modem rail; buttons assert each signal low.
MODEM 1
MODEM STATUS AND LOCAL CONTROLS

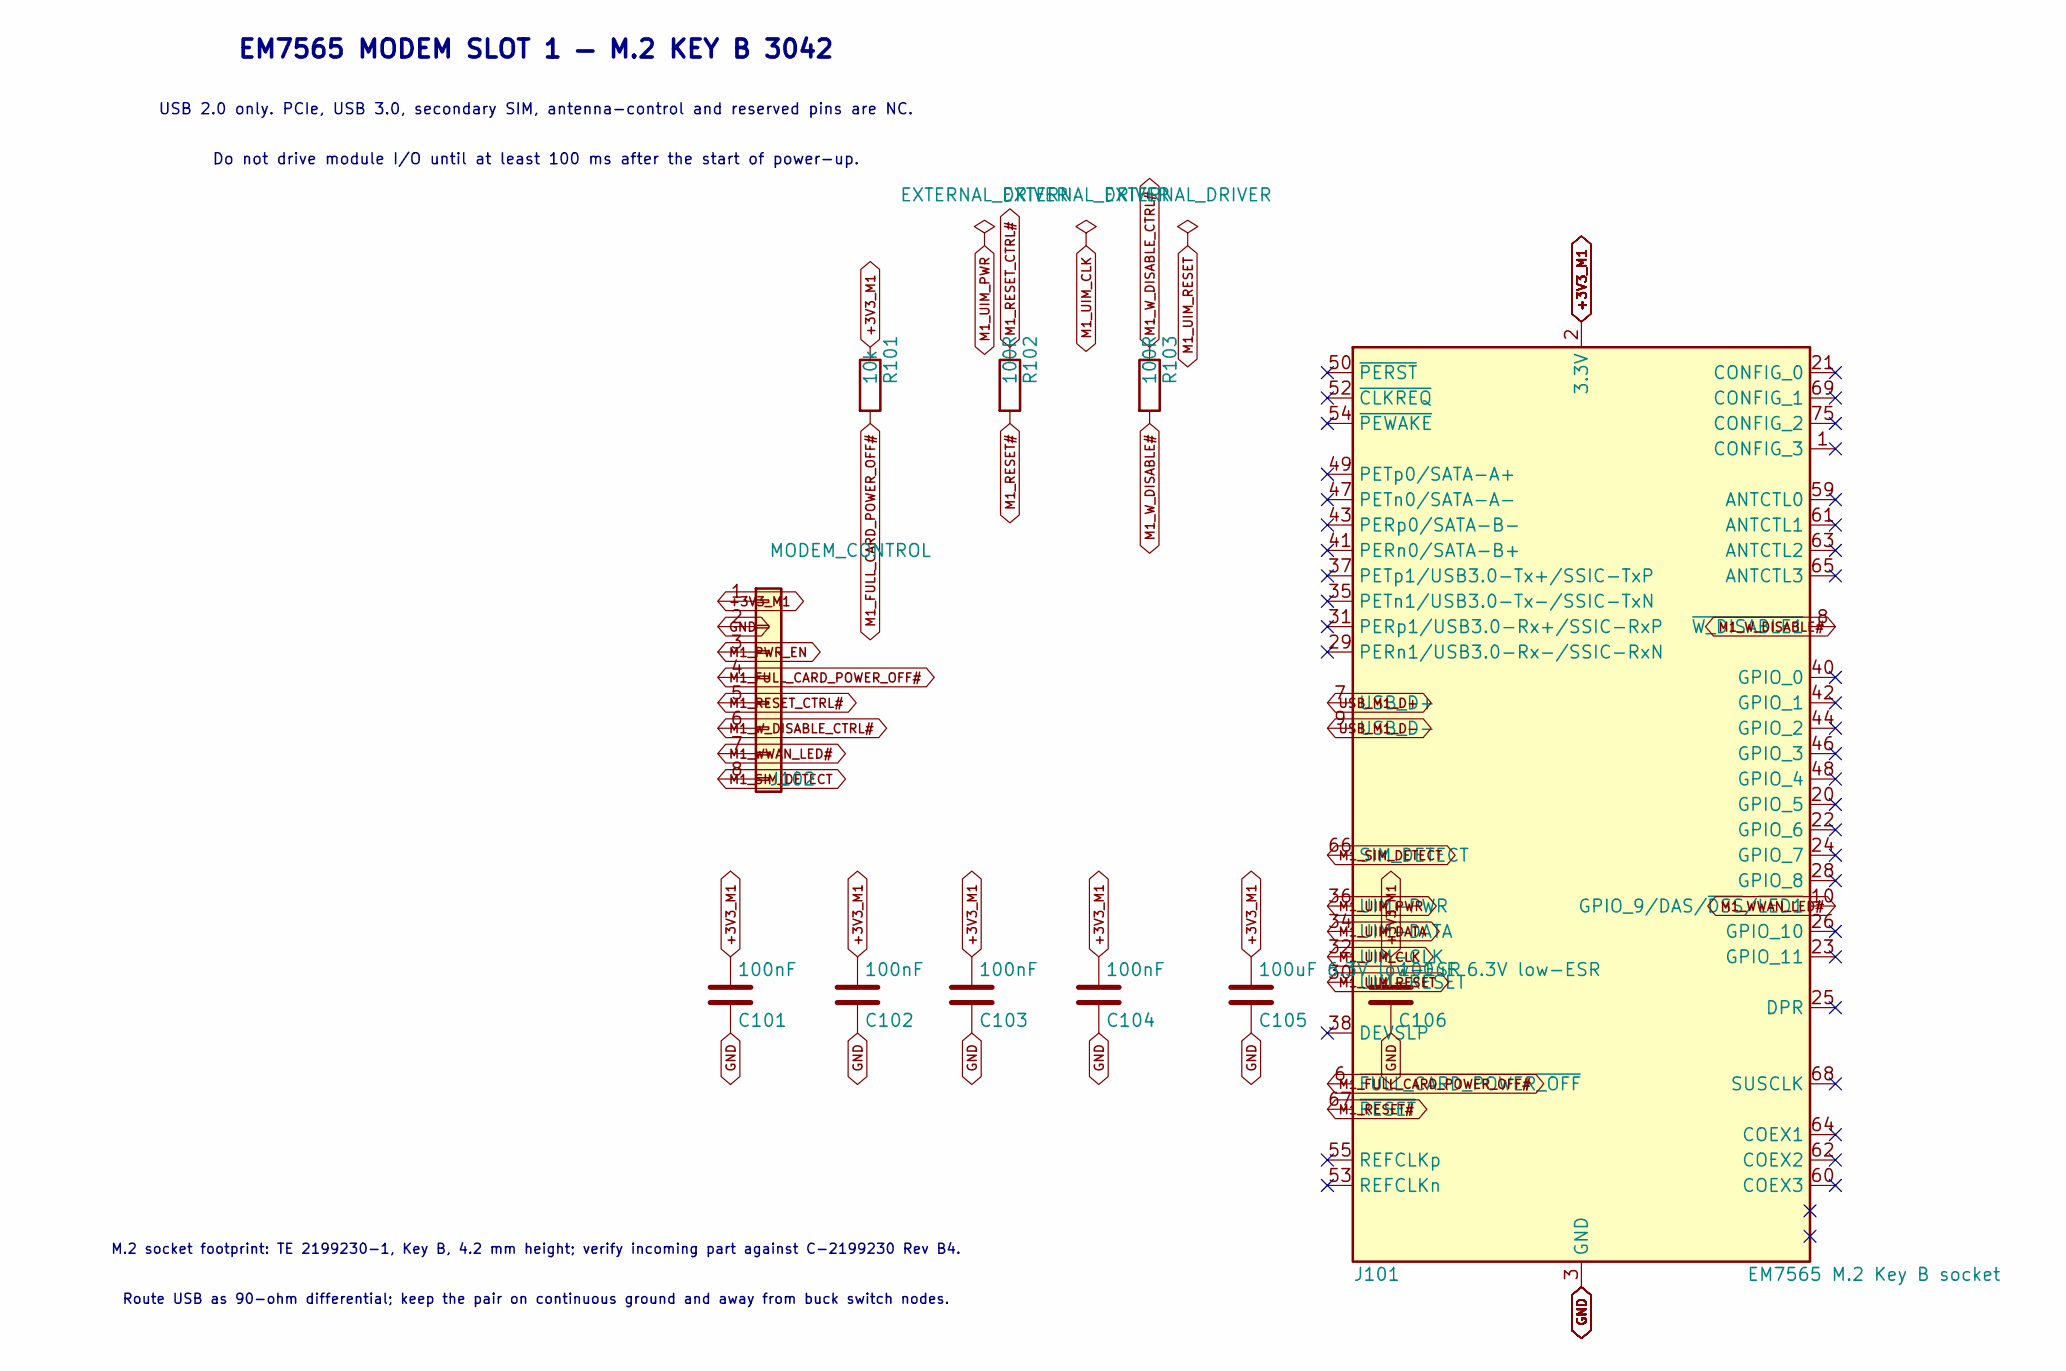
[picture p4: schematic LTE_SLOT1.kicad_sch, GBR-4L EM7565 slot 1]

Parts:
C101, C102, C103, C104: 100nF; C_0603_1608Metric
C105, C106: 100uF 6.3V low-ESR; C_1210_3225Metric
J101: EM7565 M.2 Key B socket; TE_2199230-1_M2_Key-B
J102: MODEM_CONTROL; PinHeader_1x08_P2.54mm_Vertical
R101: 10k; R_0603_1608Metric
R102, R103: 100R; R_0603_1608Metric

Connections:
+3V3_M1: C101.1, C102.1, C103.1, C104.1, C105.1, C106.1, J101.2 (3.3V), J101.4 (3.3V), J101.70 (3.3V), J101.72 (3.3V), J101.74 (3.3V), J102.1, R101.1; also elsewhere on the board
GND: C101.2, C102.2, C103.2, C104.2, C105.2, C106.2, J101.3 (GND), J101.5 (GND), J101.11 (GND), J101.27 (GND), J101.33 (GND), J101.39 (GND), J101.45 (GND), J101.51 (GND), J101.57 (GND), J101.71 (GND), J101.73 (GND), J102.2; also elsewhere on the board
M1_FULL_CARD_POWER_OFF#: J101.6 (~FULL_CARD_POWER_OFF), J102.4, R101.2
M1_PWR_EN: J102.3; also elsewhere on the board
M1_RESET#: J101.67 (~RESET), R102.2
M1_RESET_CTRL#: J102.5, R102.1; also elsewhere on the board
M1_SIM_DETECT: J101.66 (SIM_DETECT), J102.8; also elsewhere on the board
M1_UIM_CLK: J101.32 (UIM-CLK); also elsewhere on the board
M1_UIM_DATA: J101.34 (UIM-DATA); also elsewhere on the board
M1_UIM_PWR: J101.36 (UIM-PWR); also elsewhere on the board
M1_UIM_RESET: J101.30 (UIM-RESET); also elsewhere on the board
M1_WWAN_LED#: J101.10 (GPIO_9/DAS/~DSS/~LED1), J102.7; also elsewhere on the board
M1_W_DISABLE#: J101.8 (~W_DISABLE1), R103.2
M1_W_DISABLE_CTRL#: J102.6, R103.1; also elsewhere on the board
USB_M1_D+: J101.7 (USB_D+); also elsewhere on the board
USB_M1_D-: J101.9 (USB_D-); also elsewhere on the board

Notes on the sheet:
Do not drive module I/O until at least 100 ms after the start of power-up.
M.2 socket footprint: TE 2199230-1, Key B, 4.2 mm height; verify incoming part against C-2199230 Rev B4.
EM7565 MODEM SLOT 1 — M.2 KEY B 3042
USB 2.0 only. PCIe, USB 3.0, secondary SIM, antenna-control and reserved pins are NC.
Route USB as 90-ohm differential; keep the pair on continuous ground and away from buck switch nodes.

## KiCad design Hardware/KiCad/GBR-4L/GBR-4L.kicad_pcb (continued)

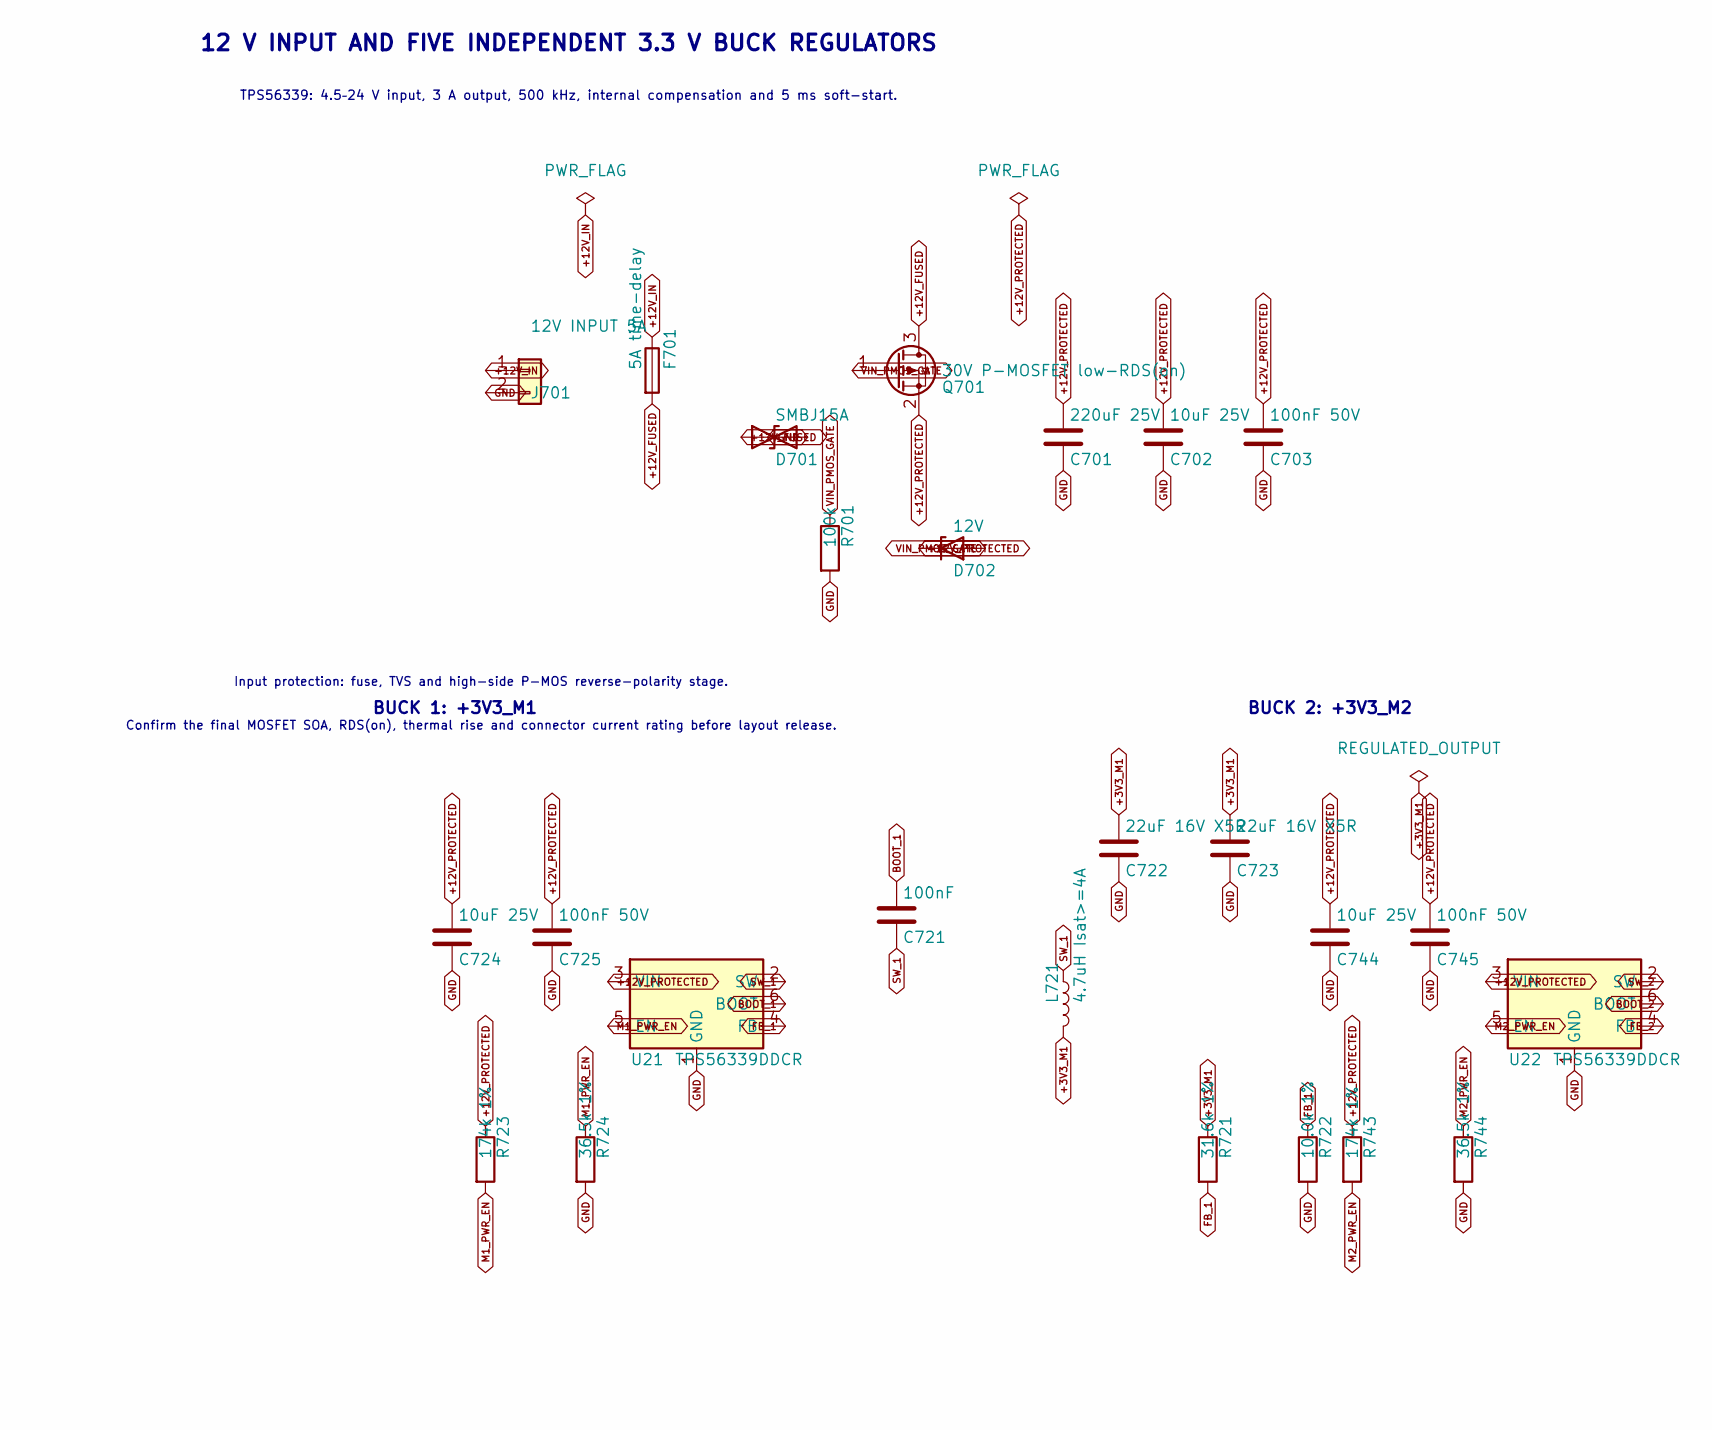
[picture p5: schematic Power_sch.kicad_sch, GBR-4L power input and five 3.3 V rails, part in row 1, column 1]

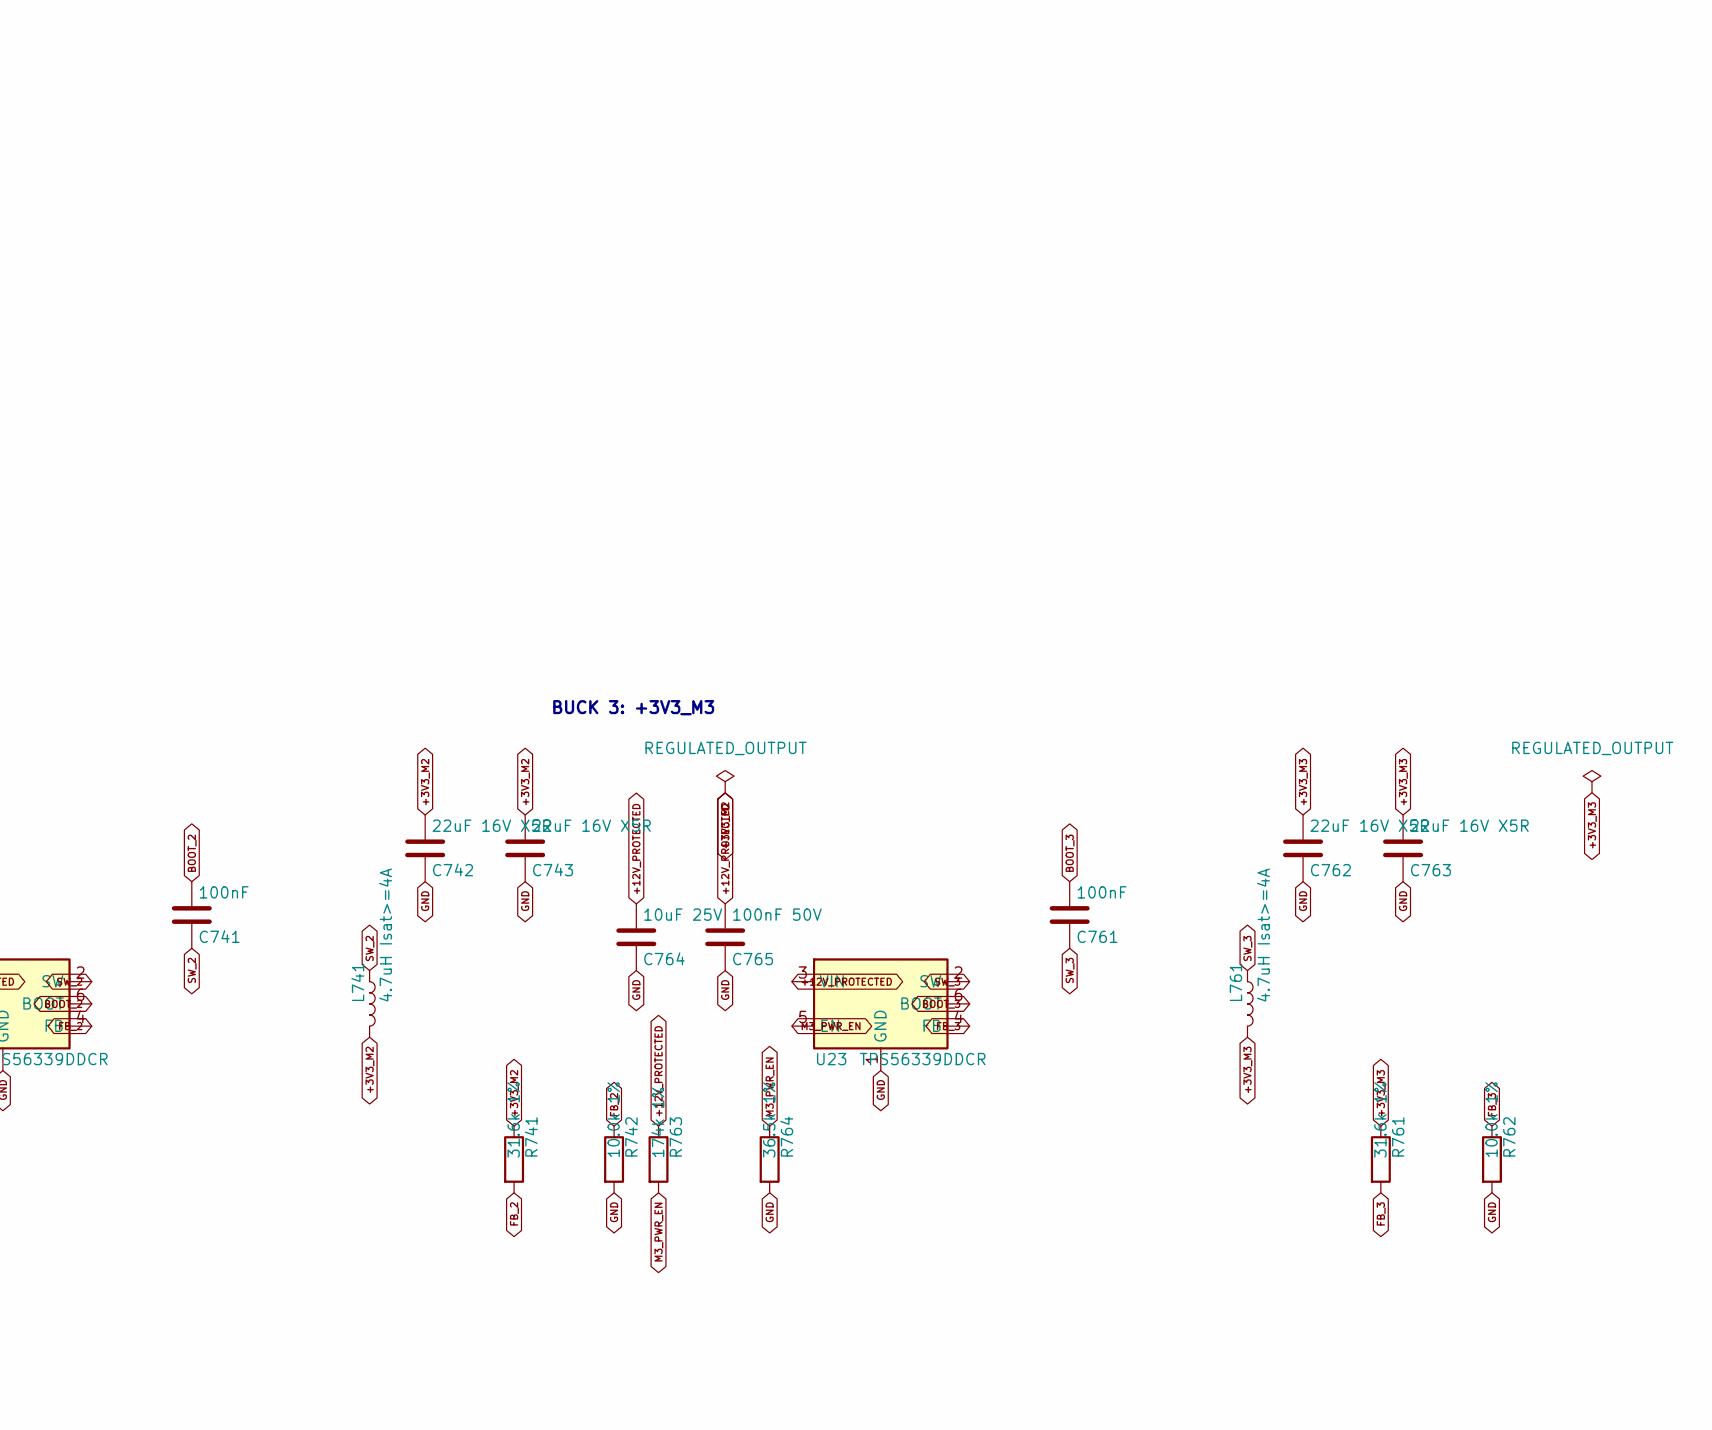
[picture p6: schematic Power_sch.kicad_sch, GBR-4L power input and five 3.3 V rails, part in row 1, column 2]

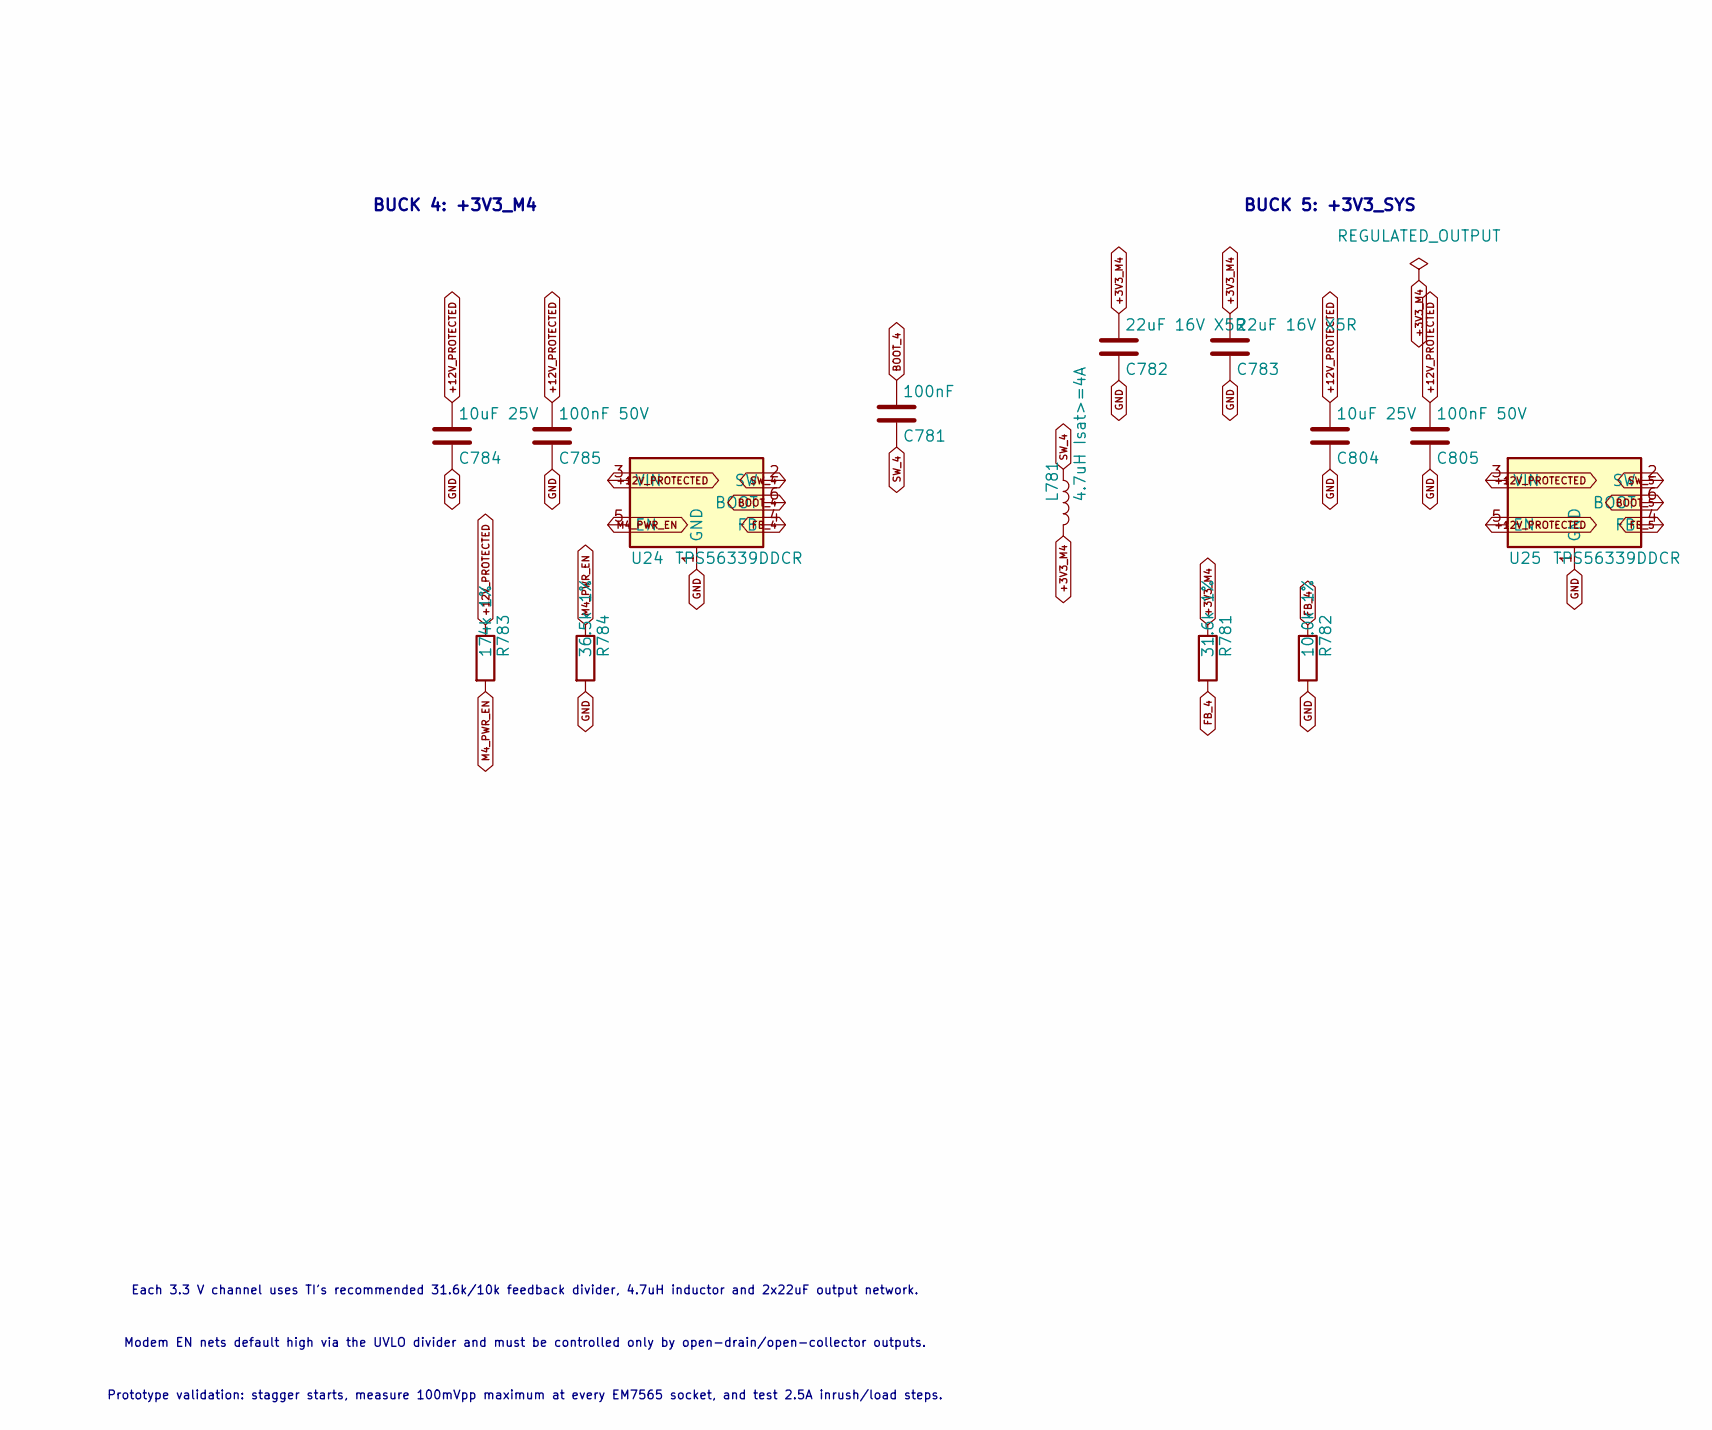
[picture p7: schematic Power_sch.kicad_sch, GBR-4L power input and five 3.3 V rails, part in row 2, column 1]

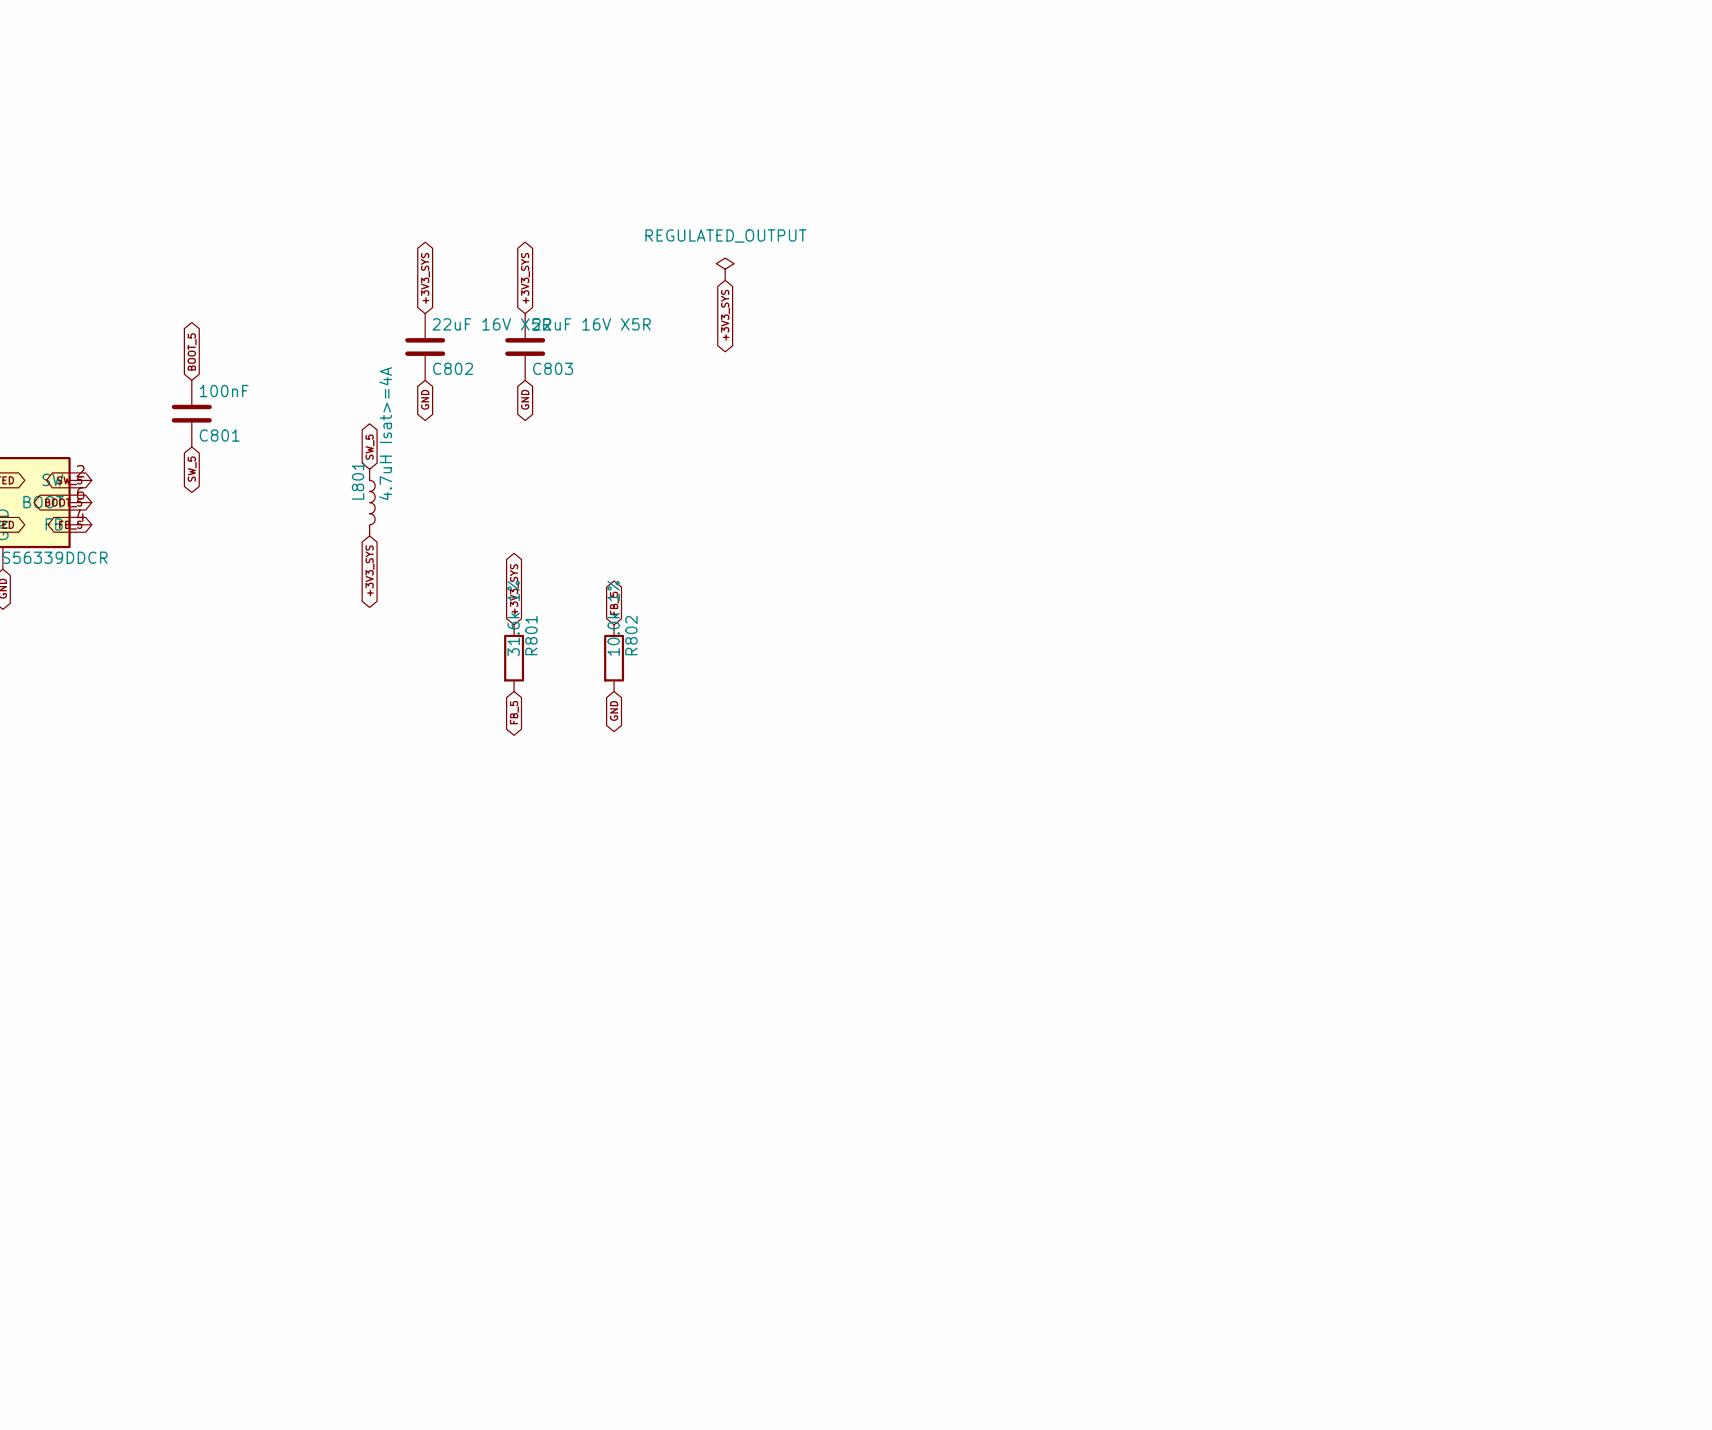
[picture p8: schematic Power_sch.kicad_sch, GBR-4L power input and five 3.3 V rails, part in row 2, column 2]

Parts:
C701: 220uF 25V; C_Elec_10x10.2
C702: 10uF 25V; C_1210_3225Metric
C703, C725, C745, C765, C785, C805: 100nF 50V; C_0603_1608Metric
C721, C741, C761, C781, C801: 100nF; C_0603_1608Metric
C722, C723, C742, C743, C762, C763, C782, C783, C802, C803: 22uF 16V X5R; C_0805_2012Metric
C724, C744, C764, C784, C804: 10uF 25V; C_0805_2012Metric
D701: SMBJ15A; D_SMB
D702: 12V; D_SOD-123
F701: 5A time-delay; Fuseholder_Blade_ATO_Littelfuse_Pudenz_2_Pin
J701: 12V INPUT 5A; TerminalBlock_Phoenix_MKDS-1,5-2_1x02_P5.00mm_Horizontal
L721, L741, L761, L781, L801: 4.7uH Isat>=4A; L_7.3x7.3_H3.5
Q701: 30V P-MOSFET low-RDS(on); TO-252-2
R701: 100k; R_0603_1608Metric
R721, R741, R761, R781, R801: 31.6k 1%; R_0603_1608Metric
R722, R742, R762, R782, R802: 10.0k 1%; R_0603_1608Metric
R723, R743, R763, R783: 174k 1%; R_0603_1608Metric
R724, R744, R764, R784: 36.5k 1%; R_0603_1608Metric
U21, U22, U23, U24, U25: TPS56339DDCR; SOT-23-6

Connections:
+3V3_M1: C722.1, C723.1, L721.2, R721.1; also elsewhere on the board
+3V3_M2: C742.1, C743.1, L741.2, R741.1; also elsewhere on the board
+3V3_M3: C762.1, C763.1, L761.2, R761.1; also elsewhere on the board
+3V3_M4: C782.1, C783.1, L781.2, R781.1; also elsewhere on the board
+3V3_SYS: C802.1, C803.1, L801.2, R801.1; also elsewhere on the board
+12V_FUSED: D701.1 (A1), F701.2, Q701.3 (D)
+12V_IN: F701.1, J701.1
+12V_PROTECTED: C701.1, C702.1, C703.1, C724.1, C725.1, C744.1, C745.1, C764.1, C765.1, C784.1, C785.1, C804.1, C805.1, D702.1 (K), Q701.2 (S), R723.1, R743.1, R763.1, R783.1, U21.3 (VIN), U22.3 (VIN), U23.3 (VIN), U24.3 (VIN), U25.3 (VIN), U25.5 (EN)
BOOT_1: C721.1, U21.6 (BOOT)
BOOT_2: C741.1, U22.6 (BOOT)
BOOT_3: C761.1, U23.6 (BOOT)
BOOT_4: C781.1, U24.6 (BOOT)
BOOT_5: C801.1, U25.6 (BOOT)
FB_1: R721.2, R722.1, U21.4 (FB)
FB_2: R741.2, R742.1, U22.4 (FB)
FB_3: R761.2, R762.1, U23.4 (FB)
FB_4: R781.2, R782.1, U24.4 (FB)
FB_5: R801.2, R802.1, U25.4 (FB)
GND: C701.2, C702.2, C703.2, C722.2, C723.2, C724.2, C725.2, C742.2, C743.2, C744.2, C745.2, C762.2, C763.2, C764.2, C765.2, C782.2, C783.2, C784.2, C785.2, C802.2, C803.2, C804.2, C805.2, D701.2 (A2), J701.2, R701.2, R722.2, R724.2, R742.2, R744.2, R762.2, R764.2, R782.2, R784.2, R802.2, U21.1 (GND), U22.1 (GND), U23.1 (GND), U24.1 (GND), U25.1 (GND); also elsewhere on the board
M1_PWR_EN: R723.2, R724.1, U21.5 (EN); also elsewhere on the board
M2_PWR_EN: R743.2, R744.1, U22.5 (EN); also elsewhere on the board
M3_PWR_EN: R763.2, R764.1, U23.5 (EN); also elsewhere on the board
M4_PWR_EN: R783.2, R784.1, U24.5 (EN); also elsewhere on the board
SW_1: C721.2, L721.1, U21.2 (SW)
SW_2: C741.2, L741.1, U22.2 (SW)
SW_3: C761.2, L761.1, U23.2 (SW)
SW_4: C781.2, L781.1, U24.2 (SW)
SW_5: C801.2, L801.1, U25.2 (SW)
VIN_PMOS_GATE: D702.2 (A), Q701.1 (G), R701.1

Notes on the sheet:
Input protection: fuse, TVS and high-side P-MOS reverse-polarity stage.
Prototype validation: stagger starts, measure 100mVpp maximum at every EM7565 socket, and test 2.5A inrush/load steps.
BUCK 1: +3V3_M1
BUCK 4: +3V3_M4
Modem EN nets default high via the UVLO divider and must be controlled only by open-drain/open-collector outputs.
12 V INPUT AND FIVE INDEPENDENT 3.3 V BUCK REGULATORS
TPS56339: 4.5–24 V input, 3 A output, 500 kHz, internal compensation and 5 ms soft-start.
BUCK 5: +3V3_SYS
BUCK 3: +3V3_M3
Confirm the final MOSFET SOA, RDS(on), thermal rise and connector current rating before layout release.
BUCK 2: +3V3_M2
Each 3.3 V channel uses TI's recommended 31.6k/10k feedback divider, 4.7uH inductor and 2x22uF output network.

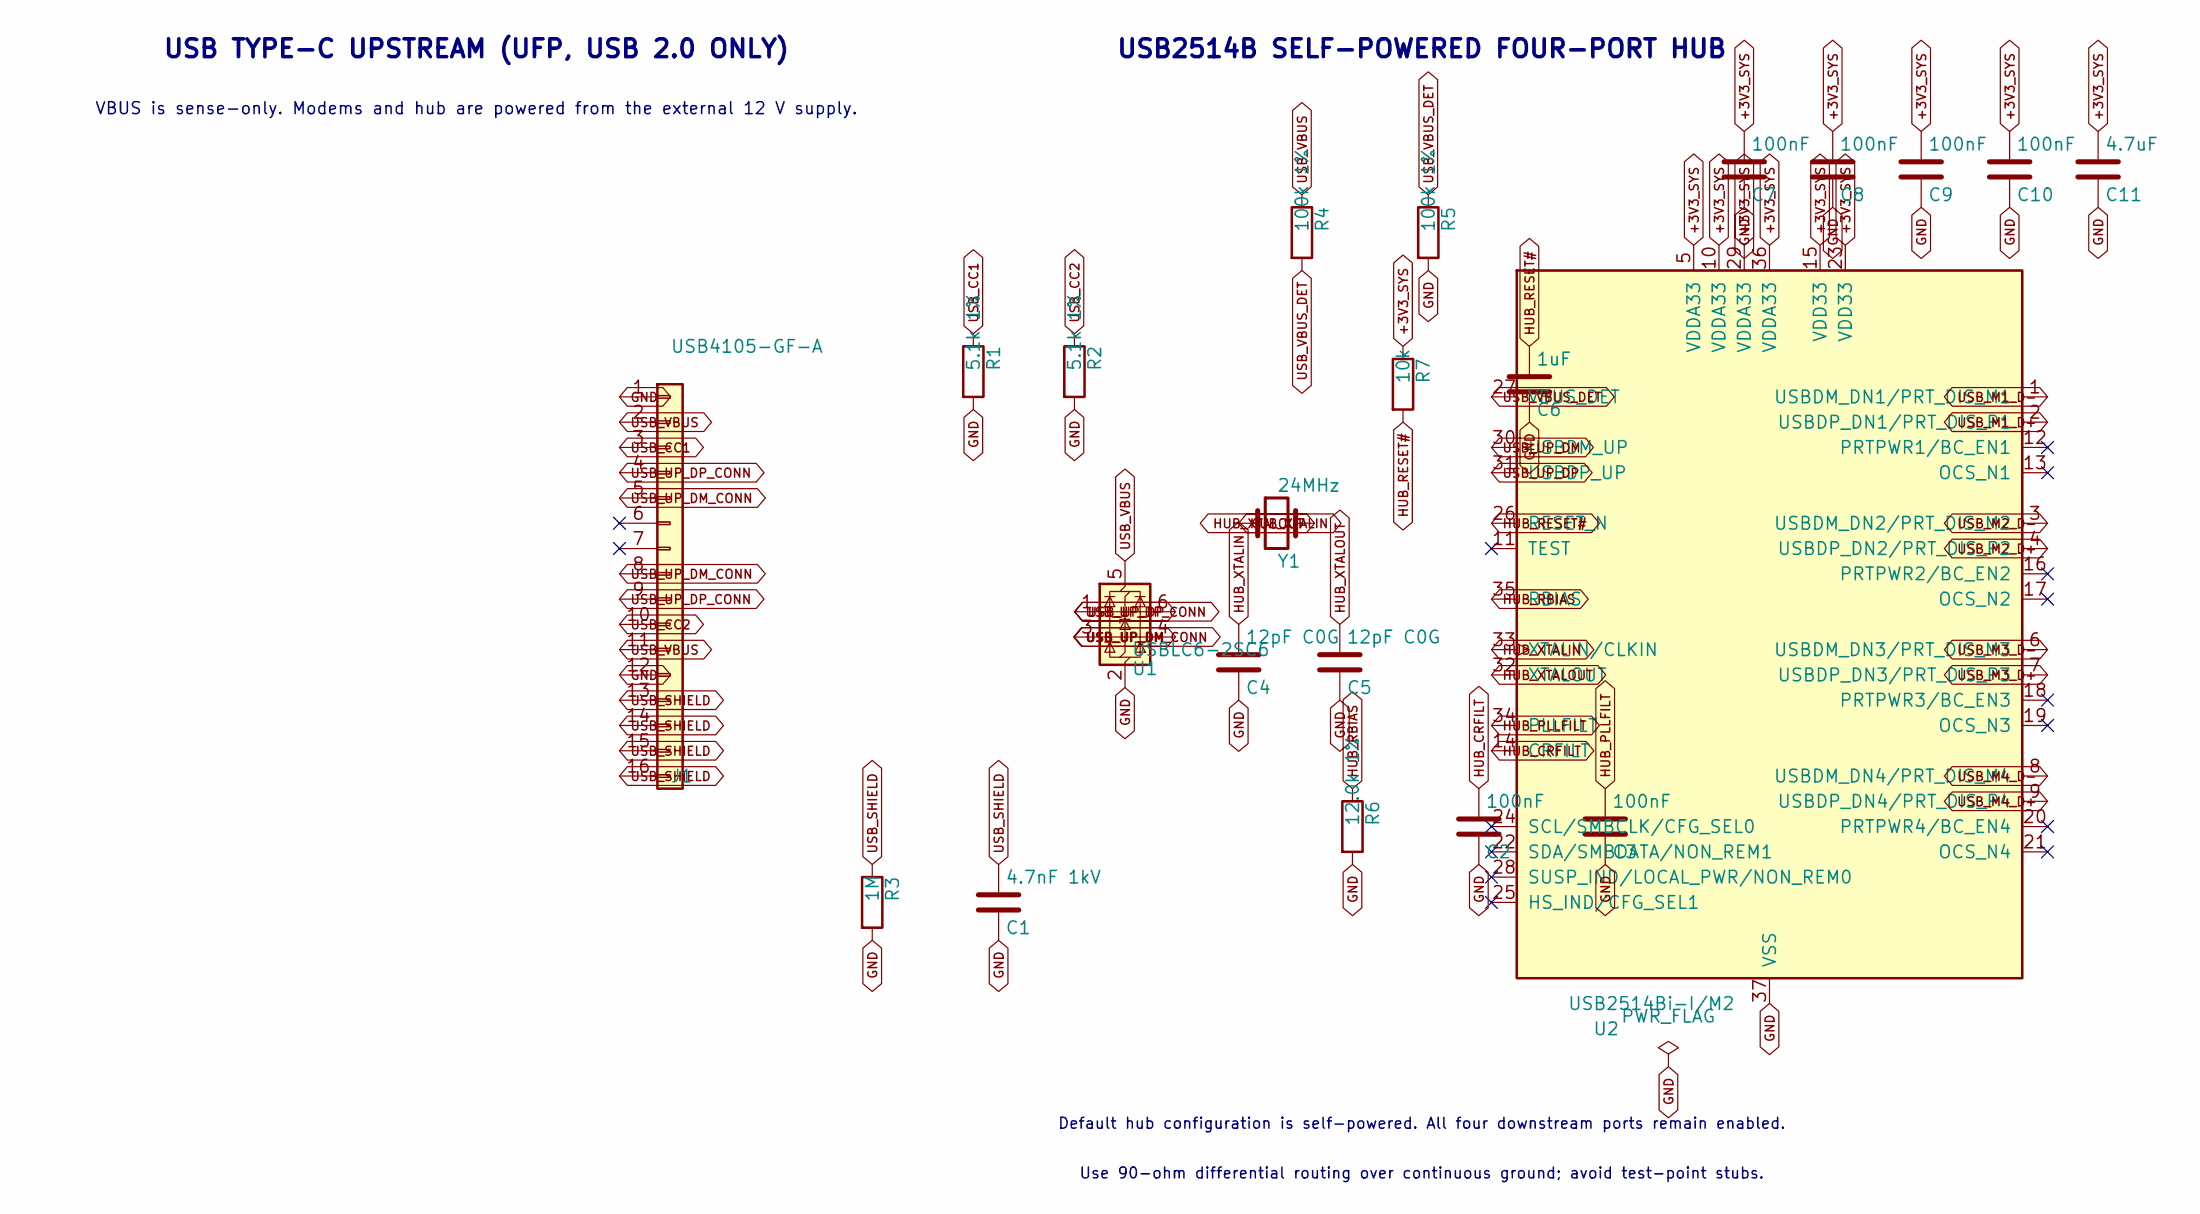
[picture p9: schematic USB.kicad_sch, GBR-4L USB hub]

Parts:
C1: 4.7nF 1kV; C_1206_3216Metric
C2, C3, C7, C8, C9, C10: 100nF; C_0603_1608Metric
C4, C5: 12pF C0G; C_0603_1608Metric
C6: 1uF; C_0603_1608Metric
C11: 4.7uF; C_0805_2012Metric
J1: USB4105-GF-A; GCT_USB4105-16P_MergedTails
R1, R2: 5.1k 1%; R_0603_1608Metric
R3: 1M; R_0603_1608Metric
R4, R5: 100k 1%; R_0603_1608Metric
R6: 12.0k 1%; R_0603_1608Metric
R7: 10k; R_0603_1608Metric
U1: USBLC6-2SC6; SOT-23-6
U2: USB2514Bi-I/M2; QFN-36-1EP_6x6mm_P0.5mm_EP4.1x4.1mm
Y1: 24MHz; Crystal_SMD_3225-4Pin_3.2x2.5mm

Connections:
+3V3_SYS: C7.1, C8.1, C9.1, C10.1, C11.1, R7.1, U2.5 (VDDA33), U2.10 (VDDA33), U2.15 (VDD33), U2.23 (VDD33), U2.29 (VDDA33), U2.36 (VDDA33); also elsewhere on the board
GND: C1.2, C2.2, C3.2, C4.2, C5.2, C6.2, C7.2, C8.2, C9.2, C10.2, C11.2, J1.1, J1.12, R1.2, R2.2, R3.2, R5.2, R6.2, U1.2 (GND), U2.37 (VSS); also elsewhere on the board
HUB_CRFILT: C2.1, U2.14 (CRFILT)
HUB_PLLFILT: C3.1, U2.34 (PLLFILT)
HUB_RBIAS: R6.1, U2.35 (RBIAS)
HUB_RESET#: C6.1, R7.2, U2.26 (RESET_N)
HUB_XTALIN: C4.1, U2.33 (XTALIN/CLKIN), Y1.1
HUB_XTALOUT: C5.1, U2.32 (XTALOUT), Y1.2
USB_CC1: J1.3, R1.1
USB_CC2: J1.10, R2.1
USB_M1_D+: U2.2 (USBDP_DN1/PRT_DIS_P1); also elsewhere on the board
USB_M1_D-: U2.1 (USBDM_DN1/PRT_DIS_M1); also elsewhere on the board
USB_M2_D+: U2.4 (USBDP_DN2/PRT_DIS_P2); also elsewhere on the board
USB_M2_D-: U2.3 (USBDM_DN2/PRT_DIS_M2); also elsewhere on the board
USB_M3_D+: U2.7 (USBDP_DN3/PRT_DIS_P3); also elsewhere on the board
USB_M3_D-: U2.6 (USBDM_DN3/PRT_DIS_M3); also elsewhere on the board
USB_M4_D+: U2.9 (USBDP_DN4/PRT_DIS_P4); also elsewhere on the board
USB_M4_D-: U2.8 (USBDM_DN4/PRT_DIS_M4); also elsewhere on the board
USB_SHIELD: C1.1, J1.13, J1.14, J1.15, J1.16, R3.1
USB_UP_DM: U1.4 (I/O2), U2.30 (USBDM_UP)
USB_UP_DM_CONN: J1.5, J1.8, U1.3 (I/O2)
USB_UP_DP: U1.6 (I/O1), U2.31 (USBDP_UP)
USB_UP_DP_CONN: J1.4, J1.9, U1.1 (I/O1)
USB_VBUS: J1.2, J1.11, R4.1, U1.5 (VBUS)
USB_VBUS_DET: R4.2, R5.1, U2.27 (VBUS_DET)

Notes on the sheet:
USB TYPE-C UPSTREAM (UFP, USB 2.0 ONLY)
USB2514B SELF-POWERED FOUR-PORT HUB
VBUS is sense-only. Modems and hub are powered from the external 12 V supply.
Default hub configuration is self-powered. All four downstream ports remain enabled.
Use 90-ohm differential routing over continuous ground; avoid test-point stubs.

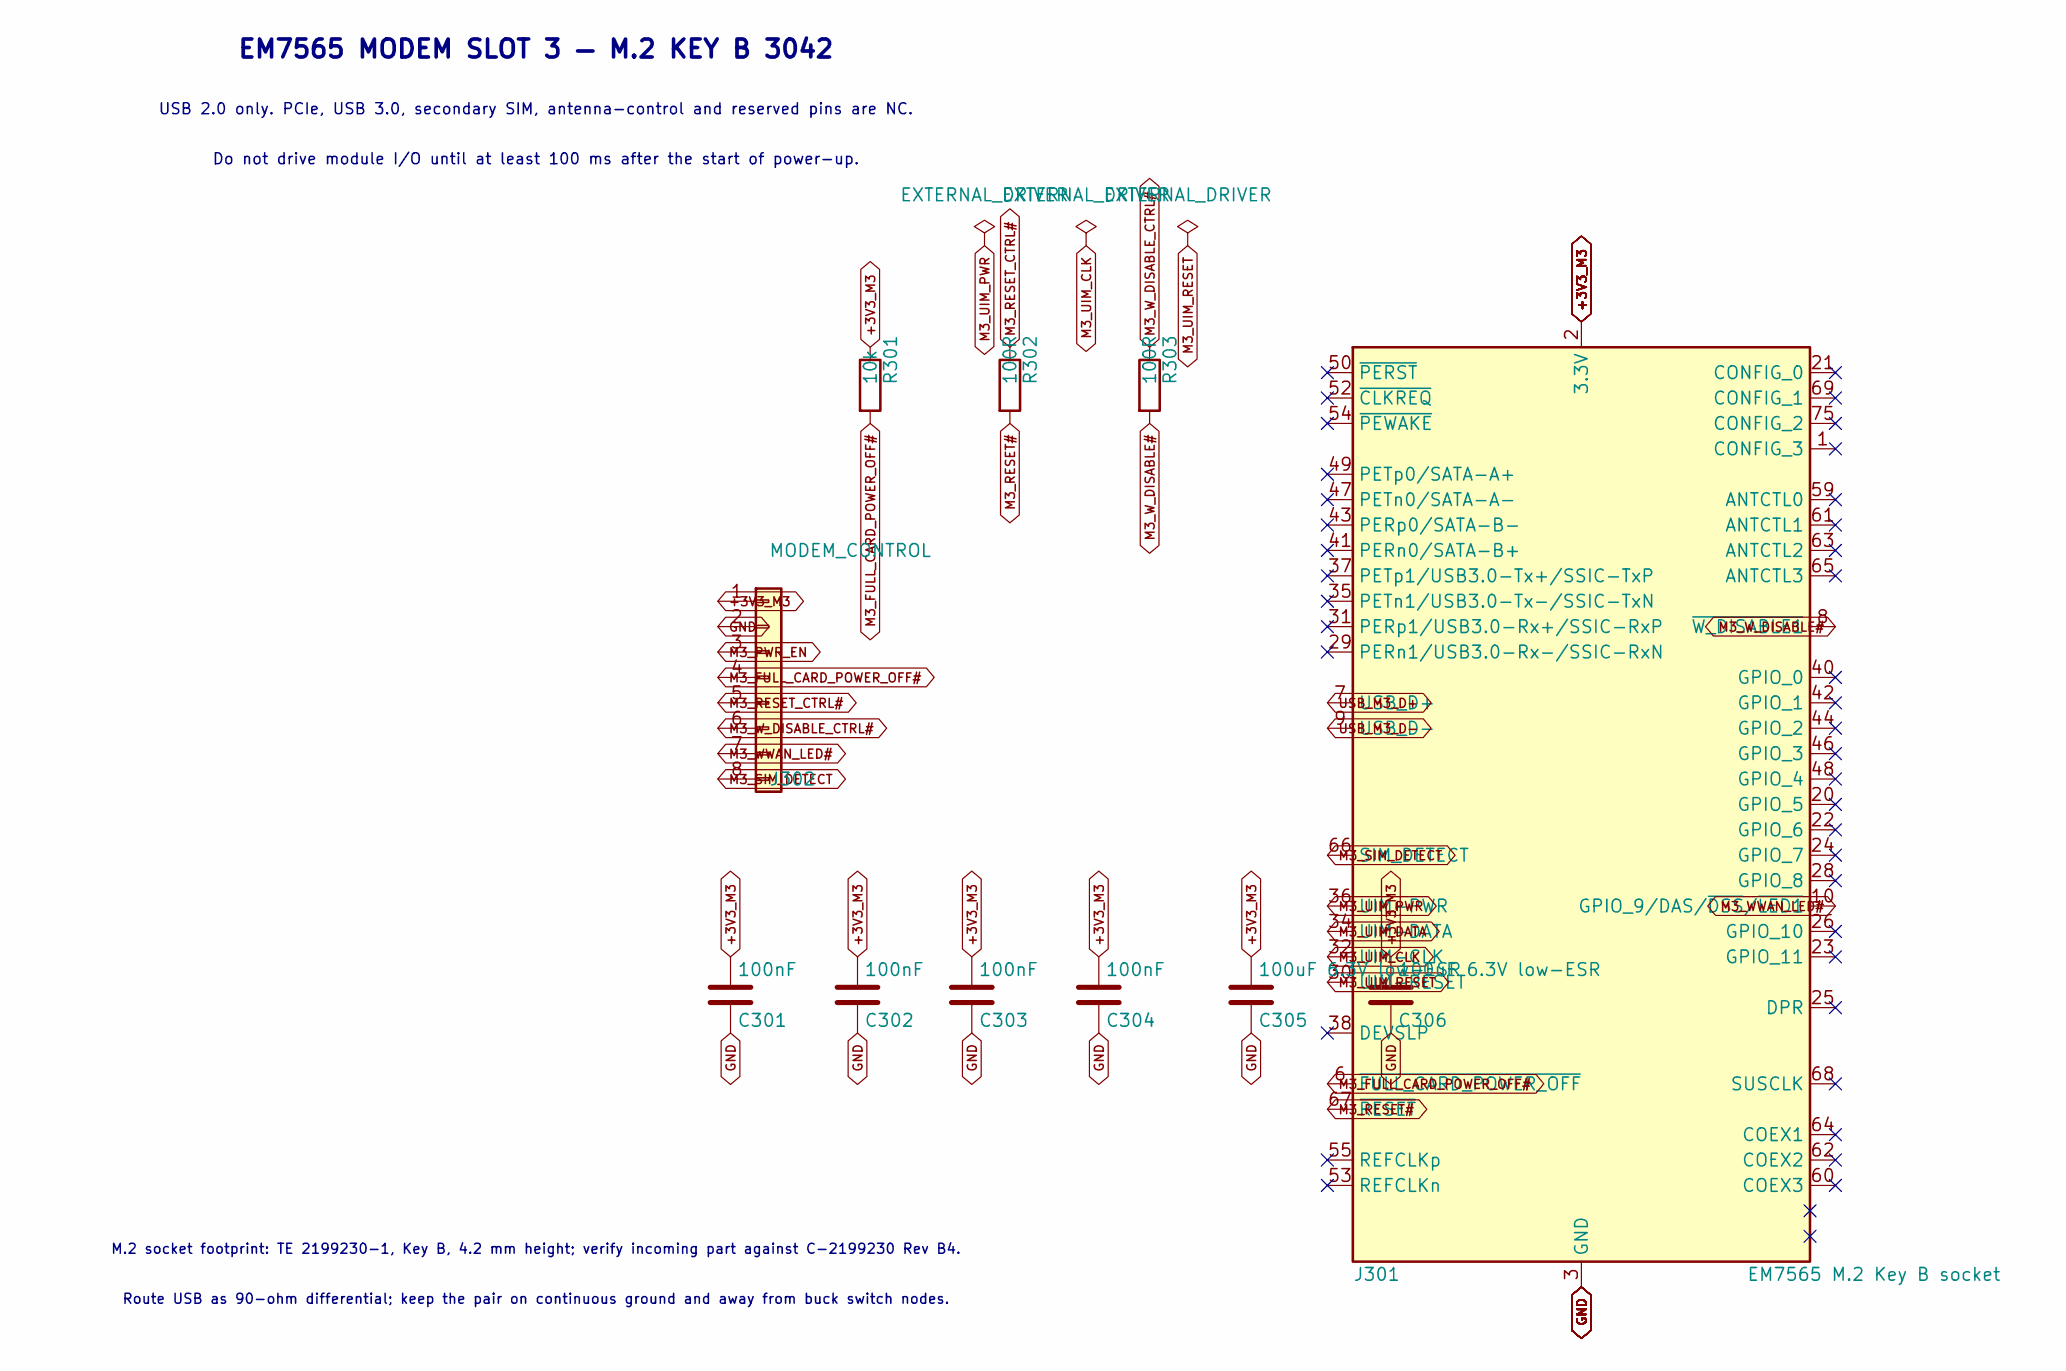
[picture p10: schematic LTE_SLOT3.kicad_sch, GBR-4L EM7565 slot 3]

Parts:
C301, C302, C303, C304: 100nF; C_0603_1608Metric
C305, C306: 100uF 6.3V low-ESR; C_1210_3225Metric
J301: EM7565 M.2 Key B socket; TE_2199230-1_M2_Key-B
J302: MODEM_CONTROL; PinHeader_1x08_P2.54mm_Vertical
R301: 10k; R_0603_1608Metric
R302, R303: 100R; R_0603_1608Metric

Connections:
+3V3_M3: C301.1, C302.1, C303.1, C304.1, C305.1, C306.1, J301.2 (3.3V), J301.4 (3.3V), J301.70 (3.3V), J301.72 (3.3V), J301.74 (3.3V), J302.1, R301.1; also elsewhere on the board
GND: C301.2, C302.2, C303.2, C304.2, C305.2, C306.2, J301.3 (GND), J301.5 (GND), J301.11 (GND), J301.27 (GND), J301.33 (GND), J301.39 (GND), J301.45 (GND), J301.51 (GND), J301.57 (GND), J301.71 (GND), J301.73 (GND), J302.2; also elsewhere on the board
M3_FULL_CARD_POWER_OFF#: J301.6 (~FULL_CARD_POWER_OFF), J302.4, R301.2
M3_PWR_EN: J302.3; also elsewhere on the board
M3_RESET#: J301.67 (~RESET), R302.2
M3_RESET_CTRL#: J302.5, R302.1; also elsewhere on the board
M3_SIM_DETECT: J301.66 (SIM_DETECT), J302.8; also elsewhere on the board
M3_UIM_CLK: J301.32 (UIM-CLK); also elsewhere on the board
M3_UIM_DATA: J301.34 (UIM-DATA); also elsewhere on the board
M3_UIM_PWR: J301.36 (UIM-PWR); also elsewhere on the board
M3_UIM_RESET: J301.30 (UIM-RESET); also elsewhere on the board
M3_WWAN_LED#: J301.10 (GPIO_9/DAS/~DSS/~LED1), J302.7; also elsewhere on the board
M3_W_DISABLE#: J301.8 (~W_DISABLE1), R303.2
M3_W_DISABLE_CTRL#: J302.6, R303.1; also elsewhere on the board
USB_M3_D+: J301.7 (USB_D+); also elsewhere on the board
USB_M3_D-: J301.9 (USB_D-); also elsewhere on the board

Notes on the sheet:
M.2 socket footprint: TE 2199230-1, Key B, 4.2 mm height; verify incoming part against C-2199230 Rev B4.
Do not drive module I/O until at least 100 ms after the start of power-up.
EM7565 MODEM SLOT 3 — M.2 KEY B 3042
Route USB as 90-ohm differential; keep the pair on continuous ground and away from buck switch nodes.
USB 2.0 only. PCIe, USB 3.0, secondary SIM, antenna-control and reserved pins are NC.

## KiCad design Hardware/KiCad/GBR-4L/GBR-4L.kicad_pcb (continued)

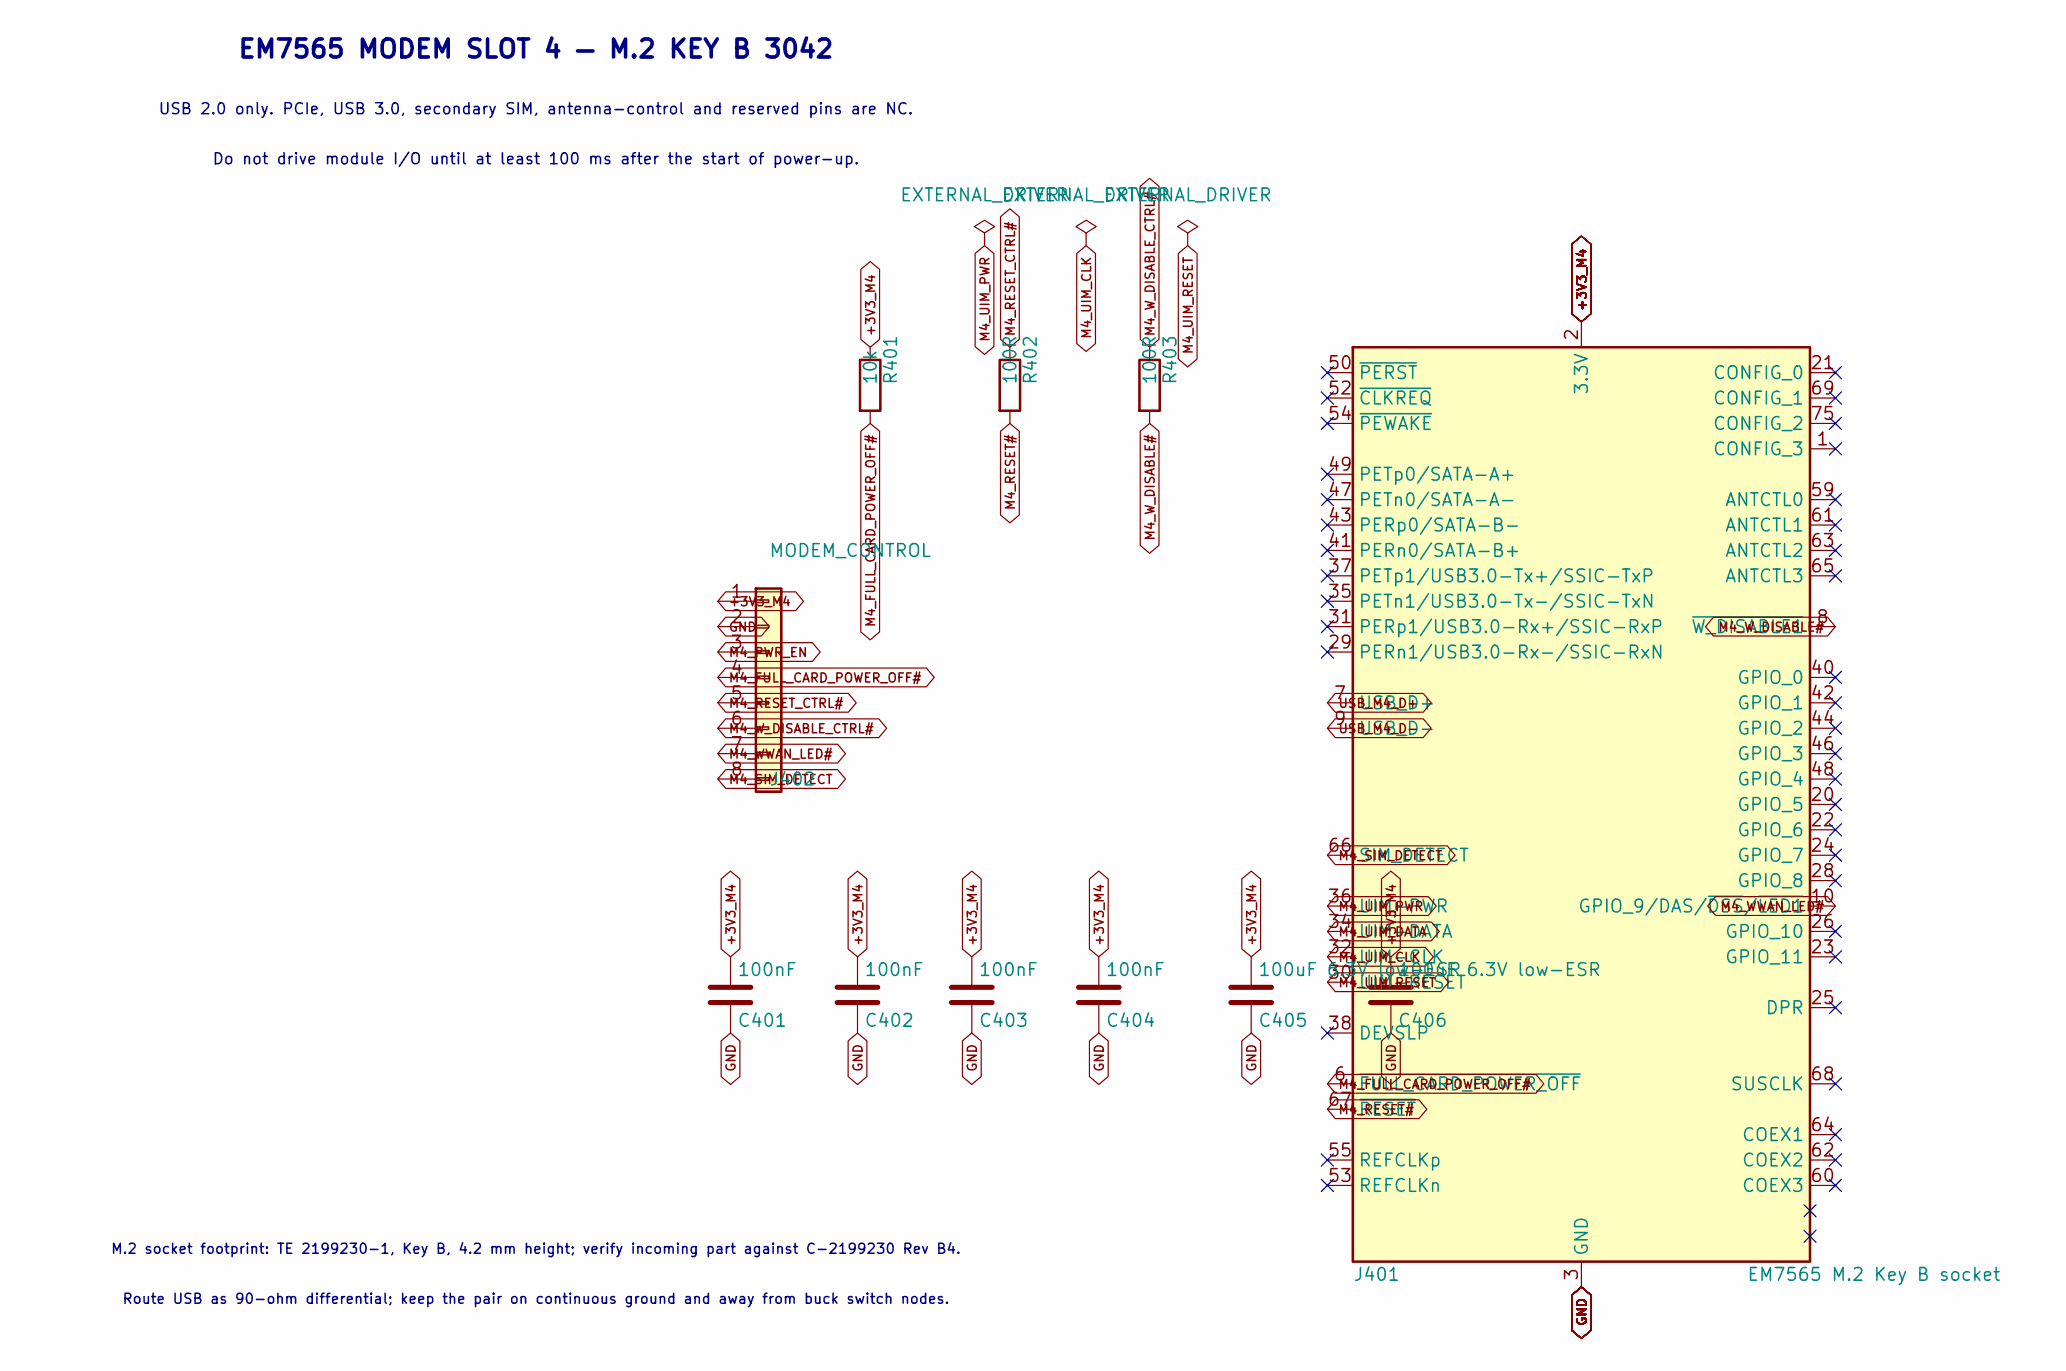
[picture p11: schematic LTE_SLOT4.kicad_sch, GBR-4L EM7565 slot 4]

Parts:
C401, C402, C403, C404: 100nF; C_0603_1608Metric
C405, C406: 100uF 6.3V low-ESR; C_1210_3225Metric
J401: EM7565 M.2 Key B socket; TE_2199230-1_M2_Key-B
J402: MODEM_CONTROL; PinHeader_1x08_P2.54mm_Vertical
R401: 10k; R_0603_1608Metric
R402, R403: 100R; R_0603_1608Metric

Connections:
+3V3_M4: C401.1, C402.1, C403.1, C404.1, C405.1, C406.1, J401.2 (3.3V), J401.4 (3.3V), J401.70 (3.3V), J401.72 (3.3V), J401.74 (3.3V), J402.1, R401.1; also elsewhere on the board
GND: C401.2, C402.2, C403.2, C404.2, C405.2, C406.2, J401.3 (GND), J401.5 (GND), J401.11 (GND), J401.27 (GND), J401.33 (GND), J401.39 (GND), J401.45 (GND), J401.51 (GND), J401.57 (GND), J401.71 (GND), J401.73 (GND), J402.2; also elsewhere on the board
M4_FULL_CARD_POWER_OFF#: J401.6 (~FULL_CARD_POWER_OFF), J402.4, R401.2
M4_PWR_EN: J402.3; also elsewhere on the board
M4_RESET#: J401.67 (~RESET), R402.2
M4_RESET_CTRL#: J402.5, R402.1; also elsewhere on the board
M4_SIM_DETECT: J401.66 (SIM_DETECT), J402.8; also elsewhere on the board
M4_UIM_CLK: J401.32 (UIM-CLK); also elsewhere on the board
M4_UIM_DATA: J401.34 (UIM-DATA); also elsewhere on the board
M4_UIM_PWR: J401.36 (UIM-PWR); also elsewhere on the board
M4_UIM_RESET: J401.30 (UIM-RESET); also elsewhere on the board
M4_WWAN_LED#: J401.10 (GPIO_9/DAS/~DSS/~LED1), J402.7; also elsewhere on the board
M4_W_DISABLE#: J401.8 (~W_DISABLE1), R403.2
M4_W_DISABLE_CTRL#: J402.6, R403.1; also elsewhere on the board
USB_M4_D+: J401.7 (USB_D+); also elsewhere on the board
USB_M4_D-: J401.9 (USB_D-); also elsewhere on the board

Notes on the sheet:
Do not drive module I/O until at least 100 ms after the start of power-up.
USB 2.0 only. PCIe, USB 3.0, secondary SIM, antenna-control and reserved pins are NC.
Route USB as 90-ohm differential; keep the pair on continuous ground and away from buck switch nodes.
EM7565 MODEM SLOT 4 — M.2 KEY B 3042
M.2 socket footprint: TE 2199230-1, Key B, 4.2 mm height; verify incoming part against C-2199230 Rev B4.

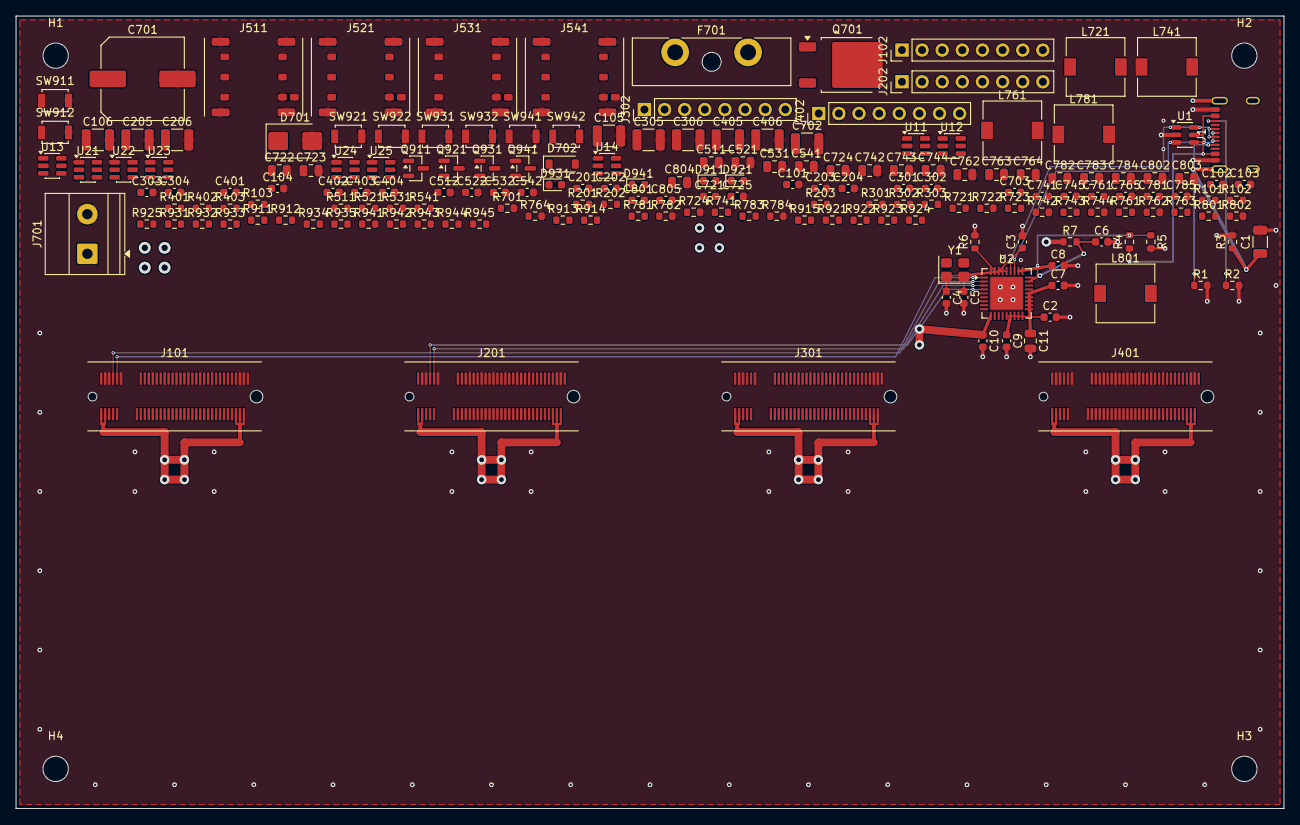
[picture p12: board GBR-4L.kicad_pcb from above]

Board: 4 copper layers, 160.0 x 100.0 mm, 188 parts (0 on the bottom side), 108 nets.

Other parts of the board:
H1, H2, H3, H4: M3; MountingHole_3.2mm_M3

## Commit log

2026-07-01 Initial project structure
    [GBR-4L.kicad_pcb, GBR-4L.kicad_sch]
2026-07-01 わかんないけど
    [GBR-4L.kicad_sch, LED_RESET.kicad_sch, LTE_SLOT1.kicad_sch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]
2026-07-02 Define Rev 1 design baseline
    [GBR-4L_Rev1_Preliminary_BOM.csv]
2026-07-02 Add USB hub schematic
    [USB.kicad_sch]
2026-07-02 Add modem and SIM schematics
    [GBR-4L_Rev1_Preliminary_BOM.csv, LTE_SLOT1.kicad_sch, LTE_SLOT2.kicad_sch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]
2026-07-02 Add protected input and five 3.3 V rails
    [GBR-4L_Rev1_Preliminary_BOM.csv, LTE_SLOT1.kicad_sch, LTE_SLOT2.kicad_sch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]
2026-07-02 Add modem status and local controls
    [GBR-4L_Rev1_Preliminary_BOM.csv, LED_RESET.kicad_sch]
2026-07-02 Add four-layer PCB mechanical baseline
    [GBR-4L.kicad_pcb]
2026-07-02 Add nano-SIM footprint and fix card detect
    [GBR-4L_Rev1_Preliminary_BOM.csv, SIM.kicad_sch]
2026-07-03 Add connector footprints and initial PCB packing
    [GBR-4L.kicad_pcb, GBR-4L_Rev1_Preliminary_BOM.csv, LED_RESET.kicad_sch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]
2026-07-03 Sync schematic nets into PCB
    [GBR-4L.kicad_pcb]
2026-07-03 Remove tracked KiCad lock file
2026-07-03 Add provisional USB and power net classes
2026-07-03 Establish functional PCB placement anchors
    [GBR-4L.kicad_pcb]
2026-07-03 Add solid inner ground plane
    [GBR-4L.kicad_pcb]
2026-07-03 Split inner power plane by supply domain
    [GBR-4L.kicad_pcb]
2026-07-04 Add modem power and ground stitching vias
    [GBR-4L.kicad_pcb]
2026-07-04 Route M.2 modem power fanouts
    [GBR-4L.kicad_pcb]
2026-07-04 Add core power plane access vias
    [GBR-4L.kicad_pcb]
2026-07-04 Add stitched outer ground pours
    [GBR-4L.kicad_pcb]
2026-07-05 Add USB connector return vias
    [GBR-4L.kicad_pcb]
2026-07-05 Place USB ESD clamp at connector
    [GBR-4L.kicad_pcb]
2026-07-05 Place USB shield termination network
    [GBR-4L.kicad_pcb]
2026-07-05 Place USB Type-C CC pull-downs
    [GBR-4L.kicad_pcb]
2026-07-05 Place USB hub and thermal vias
    [GBR-4L.kicad_pcb]
2026-07-06 Place and route USB hub oscillator
    [GBR-4L.kicad_pcb]
2026-07-06 Place and route USB hub filters
    [GBR-4L.kicad_pcb]
2026-07-06 Place and route USB hub decoupling
    [GBR-4L.kicad_pcb]
2026-07-06 Connect USB hub to system power plane
    [GBR-4L.kicad_pcb]
2026-07-06 Place and route USB hub reset network
    [GBR-4L.kicad_pcb]
2026-07-07 Place and route USB VBUS detect divider
    [GBR-4L.kicad_pcb]
2026-07-07 Route USB VBUS entry to detector
    [GBR-4L.kicad_pcb]
2026-07-07 Route USB Type-C CC pull-downs
    [GBR-4L.kicad_pcb]
2026-07-08 Route USB connector pair to ESD clamp
    [GBR-4L.kicad_pcb]
2026-07-08 Route upstream USB pair to hub
    [GBR-4L.kicad_pcb]
2026-07-09 Add USB upstream return vias
    [GBR-4L.kicad_pcb]
2026-07-10 Route USB hub port 1 to modem slot
    [GBR-4L.kicad_pcb]
2026-07-10 Route USB hub port 2 to modem slot
    [GBR-4L.kicad_pcb]
